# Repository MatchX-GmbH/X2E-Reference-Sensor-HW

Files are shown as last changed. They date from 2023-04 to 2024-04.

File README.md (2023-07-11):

# MatchX X2E Reference Sensor

## Introduction

MatchX X2E Reference Design is a universal platform to help you start your custom X2E application. It is completely open source so you can use it as a starting point for development and testing of your custom LPWAN sensor. It provides all hardware and software features to kickstart your development including LoRa (SubGHz and 2.4GHz) radios, set of sensors and GPS receiver. It is built around the ESP32-S3 module and has a friendly Arduino-compatible form factor.

## Hardware

The main features of the board include:

- ESP32-S3-MINI-1-N4R2 based, 4MB flash, 1MB PSRAM
- Arduino compatible pinout
-  Two LoRa radios: LoRa Sub-GHz and LoRa 2.4GHz
- USB-C power and debug/programming
- Grove and Stemma sensor expansion connectors
- GPS module
- Accelerometer, Air Quality, Humidity, Pressure and Temperature sensors
- Li-Ion battery connector, 2mm pitch
- Li-Ion battery charger and battery monitoring
- Ultra low Iq switching power supply for long battery operation
- User and reset buttons
- ESP-IDF programmable

## Pinout

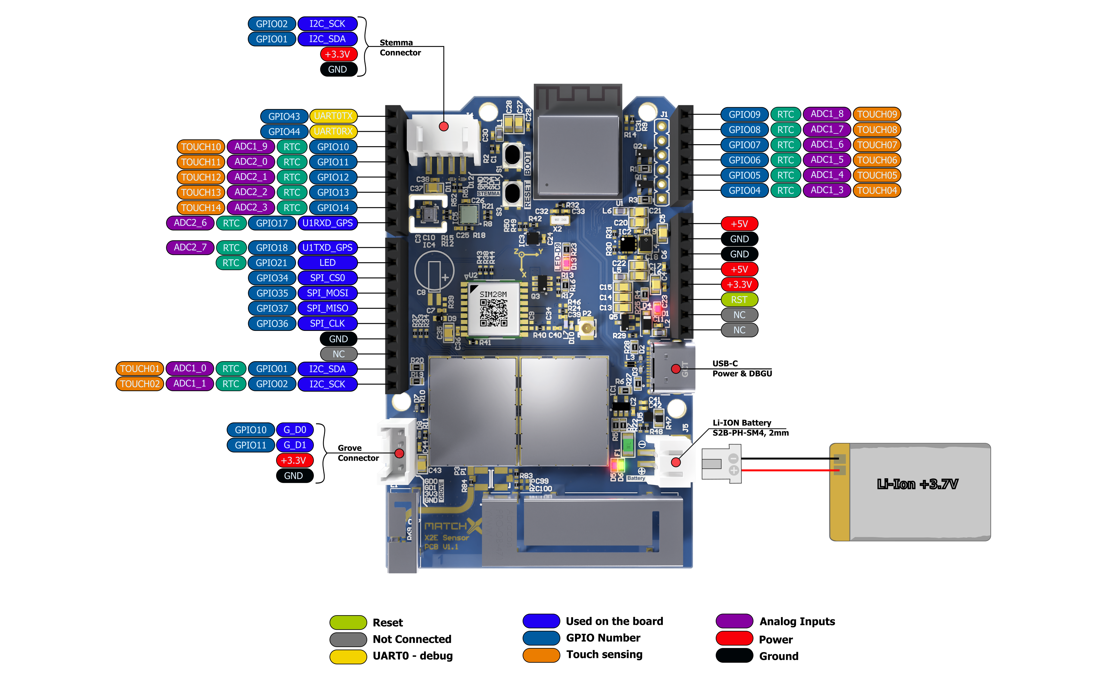
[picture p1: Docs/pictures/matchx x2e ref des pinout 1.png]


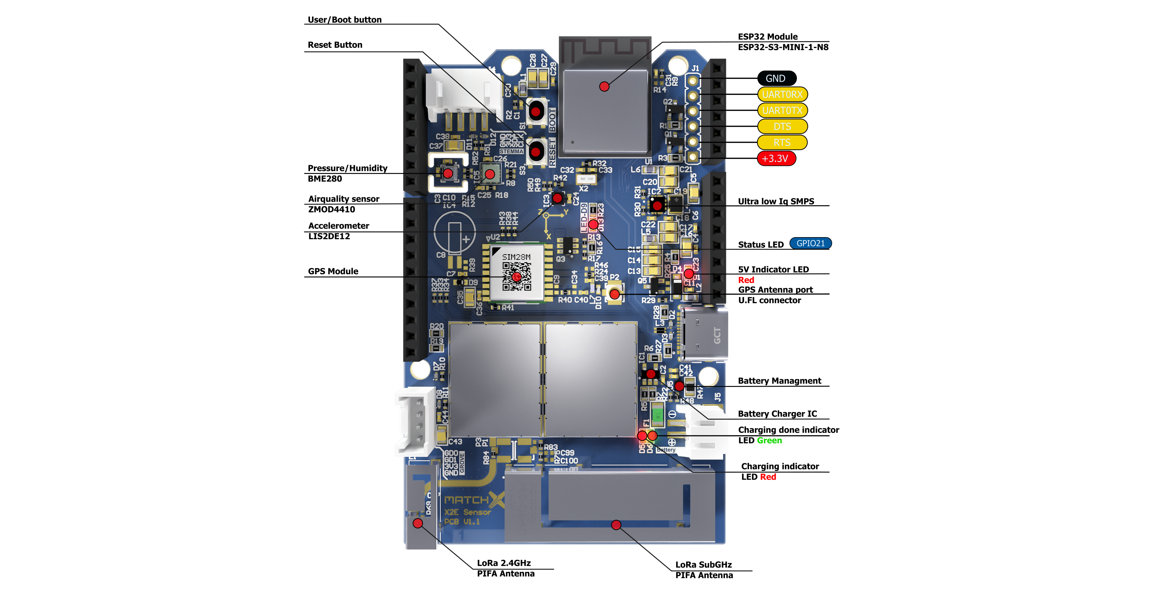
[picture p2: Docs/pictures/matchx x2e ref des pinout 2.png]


## Software

The software reference design can be found here:

## Realated documents

[ESP-IDF programming guide](https://docs.espressif.com/projects/esp-idf/en/latest/esp32s3/get-started/index.html)

[ESP32-S3 Datasheet](https://www.espressif.com/sites/default/files/documentation/esp32-s3_datasheet_en.pdf) (PDF)

[Semtech SX1261 Product Details](https://www.semtech.com/products/wireless-rf/lora-connect/sx1261) 

[Semtech SX1280 Product Details](https://www.semtech.com/products/wireless-rf/lora-connect/sx1280) 

[Low-power wide-area network - Wikipedia](https://en.wikipedia.org/wiki/Low-power_wide-area_network)

[MXCzkEVM MEP-802 Github](https://github.com/MXCzkEVM/MEPs/blob/main/proposals/mep-802.md)

## Contact Us
https://matchx.io/pages/contact-us

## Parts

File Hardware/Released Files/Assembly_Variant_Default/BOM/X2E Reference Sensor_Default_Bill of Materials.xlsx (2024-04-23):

Fitted | Designator | Quantity | Value | Description | Footprint | Manufacturer | Manufacturer Part Number | PartNumber
 | AN1 | 1 |  | Rf Ant 868MHZ/915MHZ Stamped Met | XDCR_PRO-OB-471 | Proant | PRO-OB-471
 | AN2 | 1 |  | 2.4GHz Bluetooth, WirelessHART, WLAN, Zigbee Stamped Metal RF Antenna 2.4GHz ~ 2.5GHz Solder Surface Mount | XDCR_PRO-OB-440 | Abracon | PRO-OB-440
 | C1, C3, C6, C10, C11, C23, C24, C25, C26, C29, C36, C38, C39, C44, C82, C83, C95, C96 | 18 | 100 nF | CAP, CERM, 100 nF, 50V, +/- 10%, X7R, 0402 | C0402 |  | GRM155R71H104KE14J
 | C2, C18, C19, C22, C30, C31, C41, C81, C93, C102 | 10 | 1uF/10V | CAP, CERM, 1 uF, 10V, +/- 10%, X5R, 0402 | C0402 |  | C0402C105M8PACTU
 | C4, C5, C13, C14, C15, C16, C17, C20, C21, C27, C28, C35, C37, C43, C94, C103 | 16 | 10uF | CAP, CERM, 10uF, 16V, +/- 20%, X5R, 0805 | C0805 |  | GRM21BR61C106KE15L
 | C7 | 1 | 1uF/10V | CAP, CERM, 1 uF, 10V, +/- 10%, X5R, 0402 | C0402
 | C32, C33 | 2 | 12pF | CAP, CERM, 12pF, 16V, +/- 5%, C0G/NP0, 0402 | C0402 |  | GRM0225C1C120GA03L
 | C40, C79 | 2 | 47pF | CAP, CERM, 47pF, 16V, +/- 5%, C0G/NP0, 0402 | C0402 |  | 885012005029
 | C42 | 1 | 2.2uF | CAP, CERM, 2.2uF, 10V, +/- 10%, X5R, 0402 | C0402 |  | GRM155R61A225KE01D
 | C80 | 1 | 47 nF | CAP, CERM, 47nF, 16V, +/- 10%, X7R, 0402 | C0402 |  | GCM155R71C473KA37D
 | C84 | 1 | 100pF | CAP, CERM, 100pF, 16V, +/- 5%, C0G/NP0, 0402 | C0402 |  | 885012005031
 | C86, C101 | 2 | 470nF | CAP, CERM, 470nF, 16V, +/- 10%, X7R, 0402 | C0402 |  | MSASE105AB5474KFNA01
 | C89, C97, C98 | 3 | 10nF | CAP, CERM, 10nF, 16V, +/- 10%, X7R, 0402 | C0402 |  | C0402C103J4RAC
 | C90 | 1 | 1nF | CAP, CERM, 1nF, 16V, +/- 10%, X7R, 0402 | C0402 |  | C0402C102K4RAC
 | D1 | 1 |  | Red 625nm LED Indication - Discrete 2V 0603 (1608 Metric) | LED0603 | Wurth Electronics | 150060RS75000
 | D2, D3, D7, D8, D11, D12 | 6 |  | TVS DIODE 5V 9.8V SOD923 | SOD-923 | ON Semiconductor | ESD9L5.0ST5G
 | D4 | 1 |  | DIODE GEN PURP 400V 1A SOD123F | sod123f | Diodes Incorporated | US1GWF-7
 | D5 | 1 |  | LED Low-Power Uni-Color Red 639nm 2V 2-Pin Chip LED T/R | LED0603_RA | Vishay Lite-On | LTST-S270KRKT
 | D6, D13 | 2 |  | LED GREEN CLEAR 0603 R/A SMD / LED Uni-Color Green 574nm 2-Pin Chip LED T/R | LED0603_RA | Vishay Lite-On | LTST-S270KGKT
 | D10 | 1 |  | TVS DIODE 15 V 0402 | T0402 | Murata | LXES1UTAA1-157
 | F1 | 1 | 108mR | Fuse Chip Slow Blow Acting 1A 63V SMD Solder Pad 1206 T/R UL | F1206 | Bourns | SF-1206S100-2
 | FL1 | 1 |  | Impedance-matched Filter For Sem | FP-0900FM15D0039E-MFG | Johanson | 0900FM15D0039E
 | FL2 | 1 |  | RF Filter - Lowpass | LP_FILTER_JOHANSON | Johanson | 0868LP15A020E
 | FL3 | 1 |  | Rf Filter 2.4GHZ-2.5GHZ 0402 | JT=2450FM07D0034T | Johanson | 2450FM07D0034T
 | FL4 | 1 |  | Rf Filter Low Pass 2.4GHZ 0402 | JT=2450LP07C0100T | Johanson | 2450LP07C0100T
 | IC1 | 1 |  | IC CONTROLLR LI-ION 4.2V SOT23-5 | SOT23-5 | Microchip | MCP73831T-2ATI/OT
 | IC2 | 1 |  | DC to DC Converter Buck-Boost 2.6V 1.6A 12-Pin WLP T/R | 14-FC2QFN | Maxim | MAX77827DEFD+T
 | IC3 | 1 |  | Accelerometer X, Y, Z Axis ±2g, 4g, 8g, 16g 0.5Hz ~ 2.69kHz 12-LGA (2x2) | LGA12C50P4X4_200X200X100 | STMicroelectronics | LIS2DE12TR
 | IC4 | 1 |  | SENSOR PRESSURE HUMIDITY TEMP | LGA65P250X250-8 | Bosch | BME280
 | IC5 | 1 |  | Indoor Air Quality Sensor | ZMOD4xxx_AI1_Standard | Renesas | ZMOD4410_AI1
 | IC6 | 1 |  | IC RF TxRx Only General ISM < 1GHz LoRaWAN 150MHz ~ 960MHz 24-VFQFN Exposed Pad | QFN50P400X400X80_HS-25N_Semtech | Semtech | SX1261IMLTRT
 | IC7 | 1 |  | RF Switch IC WLAN 6GHz 50 Ohm 6-QFN (1x1) | QFN50P100X100X50-6N | Skyworks Solutions | SKY13453-385LF
 | IC8 | 1 |  | IC RF TxRx Only 802.15.4 LoRa™ 2.4GHz 24-WFQFN Exposed Pad | QFN50P400X400X80_HS-25N_Semtech | Semtech | SX1280IMLTRT
 | IC9 | 1 |  | Single cell pack/system-side CEDV battery fuel (gas) gauge w/pre-programmed chemistry profiles 9-DSBGA -40 to 85 | IC_BQ27421YZFR-G1A | Texas Instruments | BQ27220YZFR
 | J2 | 1 |  | Conn USB 2.0 Type C RCP 24 POS 0.3mm/0.5mm Solder RA SMD 24 Terminal 1 Port T/R | TYPE-CF-16P-RAT-L7.3 | Global Connector Technology | USB4105-GF-A
 | J3 | 1 |  | 4 Positions Header Connector 0.079" (2.00mm) Through Hole Tin | CON-NS-TECH_1125S-4P | Seeed Studio | 110990030
 | J4 | 1 |  | CONN HEADER SMD R/A 4POS 2MM | JST S4B-PH-SM4-TB | JST Sales America Inc. | 1734827-4
 | J5 | 1 |  | CONN HEADER R/A 2POS 2MM | CON_S2B-PH-K-S | JST | S2B-PH-K-S(LF)(SN)
 | J6, J9 | 2 |  | Arduino Template | Arduino-C, Arduino-A | Harwin | M20-7820842
 | J7 | 1 |  | Arduino Template | Arduino-B | Harwin | M20-7820646
 | J8 | 1 |  | Arduino Template | Arduino-D | Harwin | M20-7821042
 | L1, L2, L5, L6, L15, L17 | 6 |  | Ferrite Beads 0603 600ohms 1.3A DCR=.15ohms | L0603 | Murata Electronics North America | BLM18KG601SH1D
 | L3 | 1 | DLP11SA350HL2L | Common Mode Filters / Chokes 35Ohm 20% 100MHz | DLP11SA350HL2L | Murata Electronics | DLP11SA350HL2L
 | L4 | 1 | 1uH/4.1A | FIXED IND 1UH 4.1A 42 MOHM SMD | L252020 | Pulse | BDHE002520121R0MQ1
 | L7 | 1 | 27nH | Inductor, Wirewound, 27 nH, 280mA , 520mOhm, SMD | L0402 | Murata | LQW15AN27NJ00D
 | L12, L14 | 2 | 47nH | Inductor, Wirewound, 47nH, 210 mA, 1.08Ohms, ±0.2nH, SMD | L0402 | Murata | LQW15AN47NJ00D
 | L13 | 1 | 15uH | Inductor, 15Uh, 0.25A, Multilayer Rohs Compliant: Yes | L0805_ML | Murata | LQM21DN150M70L
 | L16 | 1 | 15uH | Chip inductor, 15uH, 250mA, 950mOhm, 0805 | L0805_ML | TDK | MLZ2012M150WTD25
 | P2 | 1 |  | CONN UMCC JACK STR 50OHM SMD | CON_U.FL | TE Connectivity AMP Connectors | 1909763-1
 | Q1, Q2 | 2 |  | MOSFETN-CH 30V 6.2A SOT23-3 | SOT-23 | Diodes | DMN3023L-7
 | Q3 | 1 |  | Trans MOSFET N/P-CH 20V 1.34A/1.14A Automotive 6-Pin SOT-26 T/R | SOT23-6 | Diodes | DMC2700UDM-7
 | Q5 | 1 |  | MOSFET P-CH 12V 4.3A SOT-23 | SOT-23 | Infineon Technologies Americas Corp. | IRLML6401TRPBF
 | R1, R3, R16 | 3 | 1k | RES, 1k, 1%, 0.063 W, 0603 | R0603 |  | AC0603FR-101KL
 | R2, R9, R35, R36, R42, R48, R70, R79 | 8 | 10k | RES, 10k, 1%, 1/16 W, 0402 | R0402 |  | RE0402FRE0710KL
 | R4, R5 | 2 | 3k9 | RES, 3k9, 1%, 0.063 W, 0603 | R0603
 | R6 | 1 | 3k | RES, 3k, 1%, 0.063 W, 0603 | R0603 |  | AF0603FR-073KL
 | R7, R23 | 2 | 2k | RES, 2k, 1%, 0.063 W, 0603 | R0603 |  | RE0603FRE072KL
 | R8, R12, R15, R21, R30, R31, R39, R40, R49, R50, R69, R75, R83, R84 | 14 | 0R | RES, 0R, 1%, 1/16 W, 0402 | R0402 |  | AC0402FR-070RL
 | R10, R11, R24, R51, R52 | 5 | 10R | RES, 10R, 1%, 1/16 W, 0402 | R0402 |  | RC0402FR-0710RP
 | R13, R17, R29, R32 | 4 | 1M | RES, 1M, 1%, 1/16 W, 0402 | R0402 |  | RC0402FR-101ML
 | R18 | 1 | 100k | RES, 100k, 1%, 1/16 W, 0402 | R0402 |  | AC0402FR-13100KL
 | R22 | 1 | 1k | RES, 1k, 1%, 0.063 W, 0603 | R0603
 | R26 | 1 | 1k | RES, 1k, 1%, 1/16 W, 0402 | R0402
 | R27, R28 | 2 | 5k1 | RES, 5k1, 1%, 0.063 W, 0603 | R0603 |  | AC0603FR-135K1L
 | R33, R34, R37, R38, R43, R44, R72, R73, R74, R76, R77, R78 | 12 | 22R | RES, 22R, 1%, 1/16 W, 0402 | R0402 |  | RC0402FR-0722RP
 | R41 | 1 | 47k | RES, 47k, 1%, 1/16 W, 0402 | R0402 |  | RC0402FR-1347KL
 | R47 | 1 | 0.01R | RES, 10 mOhm, 1%, 1/8W, 0805 | R0805 |  | RL0805FR-070R01L
 | R71 | 1 | 100R | RES, 100R, 1%, 1/16 W, 0402 | R0402 |  | RC0402FR-13100RL
 | S1, S3 | 2 |  | Switch Tactile N.O. SPST Button 12VDC 50mA 5N SMD T/R | TS-1108A | Alps Alpine | SKRPASE010
 | SH1, SH2 | 2 |  | Shield - EMI Gasket - Standard Surface Mount Shields 14.9x18.5x2mm | SHIELD_MSTICK_SOM
 | U1 | 1 |  | WLAN-BLE Module – 802.11 SMD Module, ESP32-S3FH4R2 with 4 MB Flash Die, 2MB PSRAM, PCB Antenna | ESP32-S3-MINI-1-N4R2 | Espressif Systems | ESP32-S3-MINI-1-N4R2
 | U2 | 1 | GT-1110-UB7X | GPS, GLONASS, QZSS and SBAS Module | SIM28ML | GOTOP | GT-1110-UB7X
 | Y1 | 1 | 32.768kHz | XTAL SMD 3215, 32.768kHz, 7pF, ±20ppm | XTAL_3215 | Epson Timing | FC-135 32.7680KA-AC0
 | Y2 | 1 | 32MHz | 32MHz ±10ppm Crystal 10pF 50 Ohms 4-SMD 2016, No Lead | nd2016da | ECS International | ECS-320-10-37B-CKY
 | Y3 | 1 | 52MHz | 52 MHz Crystal 10pF 50 Ohms 4-SMD, No Lead | nd2016da | ECS | ECS-520-12-37B-CTN-TR

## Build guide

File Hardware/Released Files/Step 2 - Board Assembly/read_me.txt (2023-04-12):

Place following files here:

- Mechanical Drawing (Board dimensions, holes position, ..)
- TOP and BOTTOM Assembly Drawing (Component position with Reference Designator)
- TOP and BOTTOM VIEW (shows board outline, assembly layer, TOP + BOTTOM layers)
- Bill of Materials (grouped by component type)
- Component reference BOM (each component on one line: Designator, Description, Manufacturer 1,
  Manufacturer, Part Number 1, Package / Case, Supplier 1, Supplier Part Number 1)
- Pick and Place
- TOP and BOTTOM Layer + TOP and BOTTOM Paste Gerber Files (for stencil - if panel is done in a PCB house, ask them later for the top/bottom layers and paste for the panel)
- PDF 3D Model

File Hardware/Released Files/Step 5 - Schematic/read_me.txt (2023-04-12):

Update Schematic Cover Page to RELEASED DD-MMM-YYYY
Place here PDF version of schematic, if possible one for each BOM variant.

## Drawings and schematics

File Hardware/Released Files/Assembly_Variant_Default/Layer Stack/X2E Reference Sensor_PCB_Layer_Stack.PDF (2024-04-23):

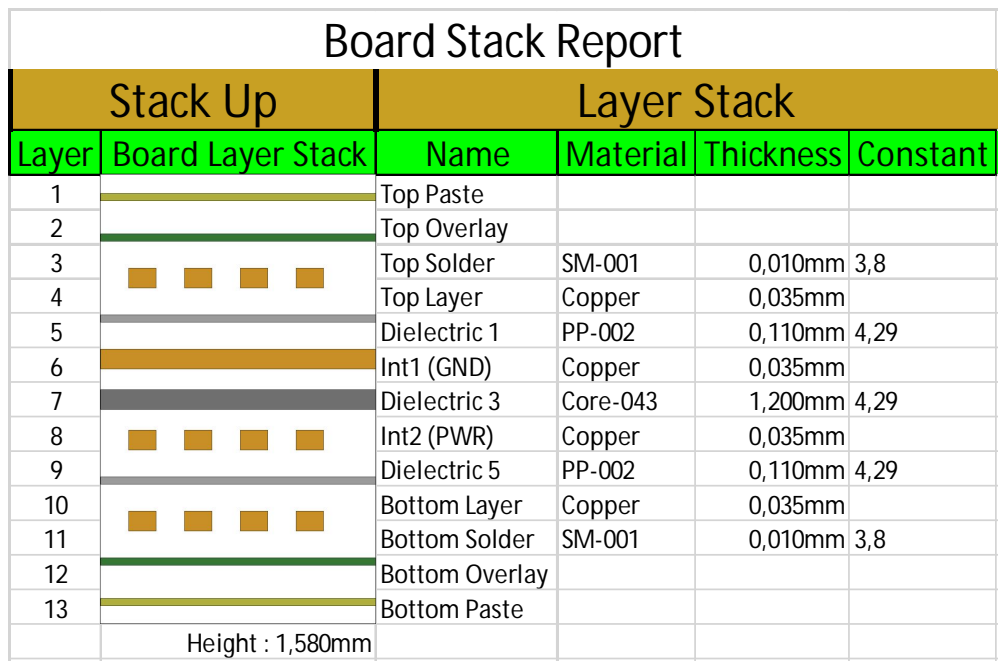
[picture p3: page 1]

Stack Up | Layer Stack
Layer | Board Layer Stack | Name | Material | Thickness | Constant
1 | | Top Paste
2 | | Top Overlay
3 | | Top Solder | SM-001 | 0,010mm | 3,8
4 | | Top Layer | Copper | 0,035mm
5 | | Dielectric 1 | PP-002 | 0,110mm | 4,29
6 | | Int1 (GND) | Copper | 0,035mm
7 | | Dielectric 3 | Core-043 | 1,200mm | 4,29
8 | | Int2 (PWR) | Copper | 0,035mm
9 | | Dielectric 5 | PP-002 | 0,110mm | 4,29
10 | | Bottom Layer | Copper | 0,035mm
11 | | Bottom Solder | SM-001 | 0,010mm | 3,8
12 | | Bottom Overlay
13 | | Bottom Paste

Height : 1,580mm

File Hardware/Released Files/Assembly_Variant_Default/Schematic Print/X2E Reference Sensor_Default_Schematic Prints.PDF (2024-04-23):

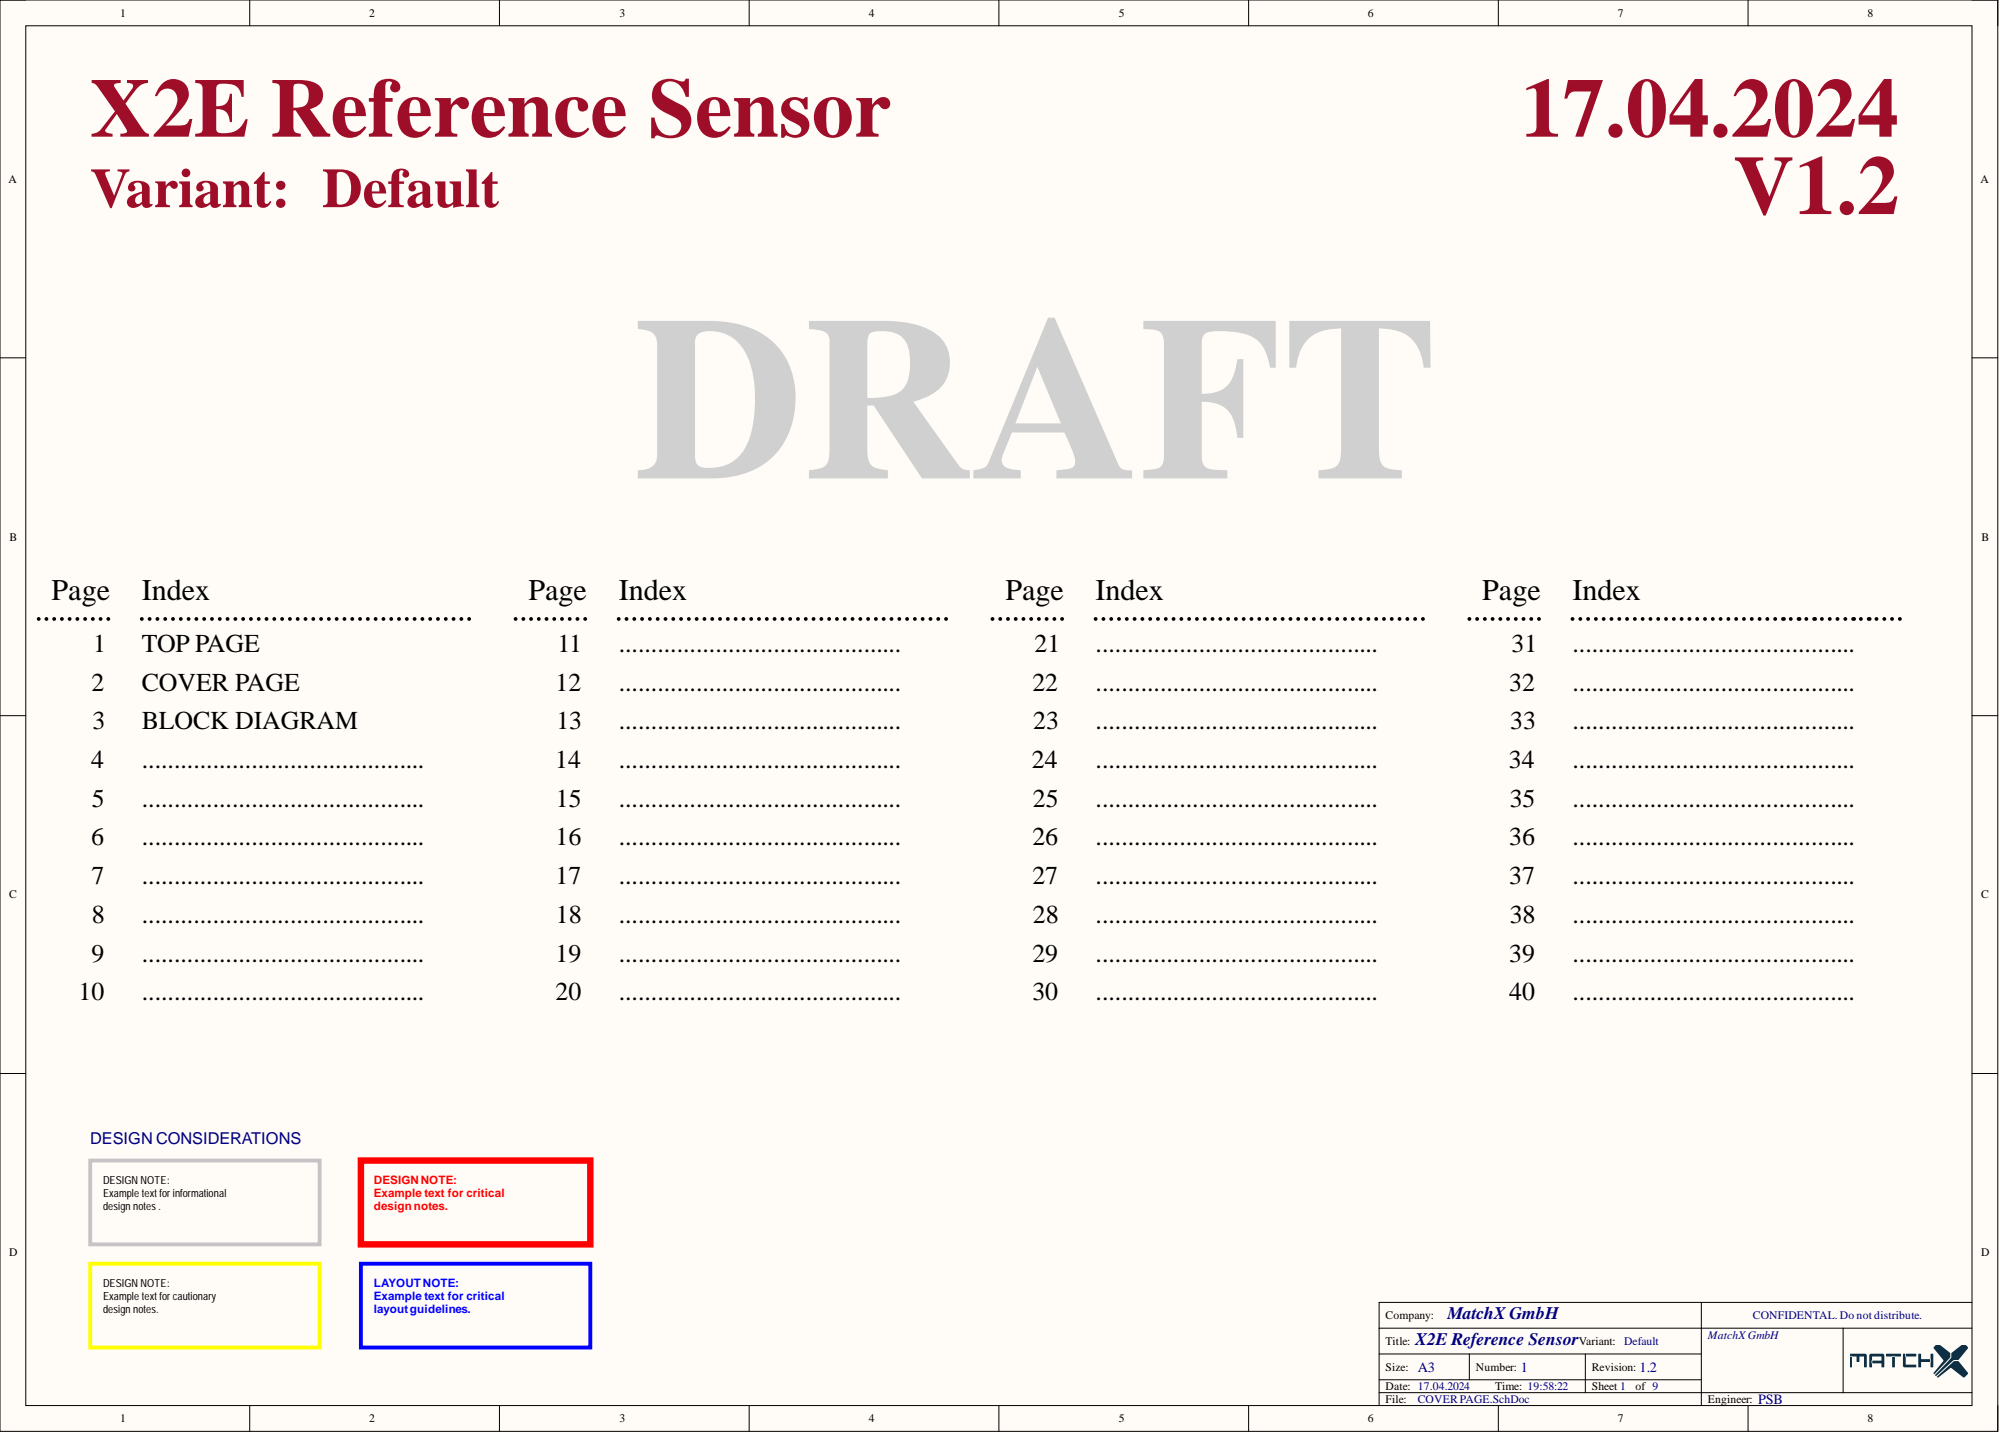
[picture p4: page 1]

DESIGN NOTE:
Example text for informational
design notes .

Example text for critical
design notes.

Example text for cautionary

LAYOUT NOTE:
layout guidelines.

CONFIDENTAL. Do not distribute.

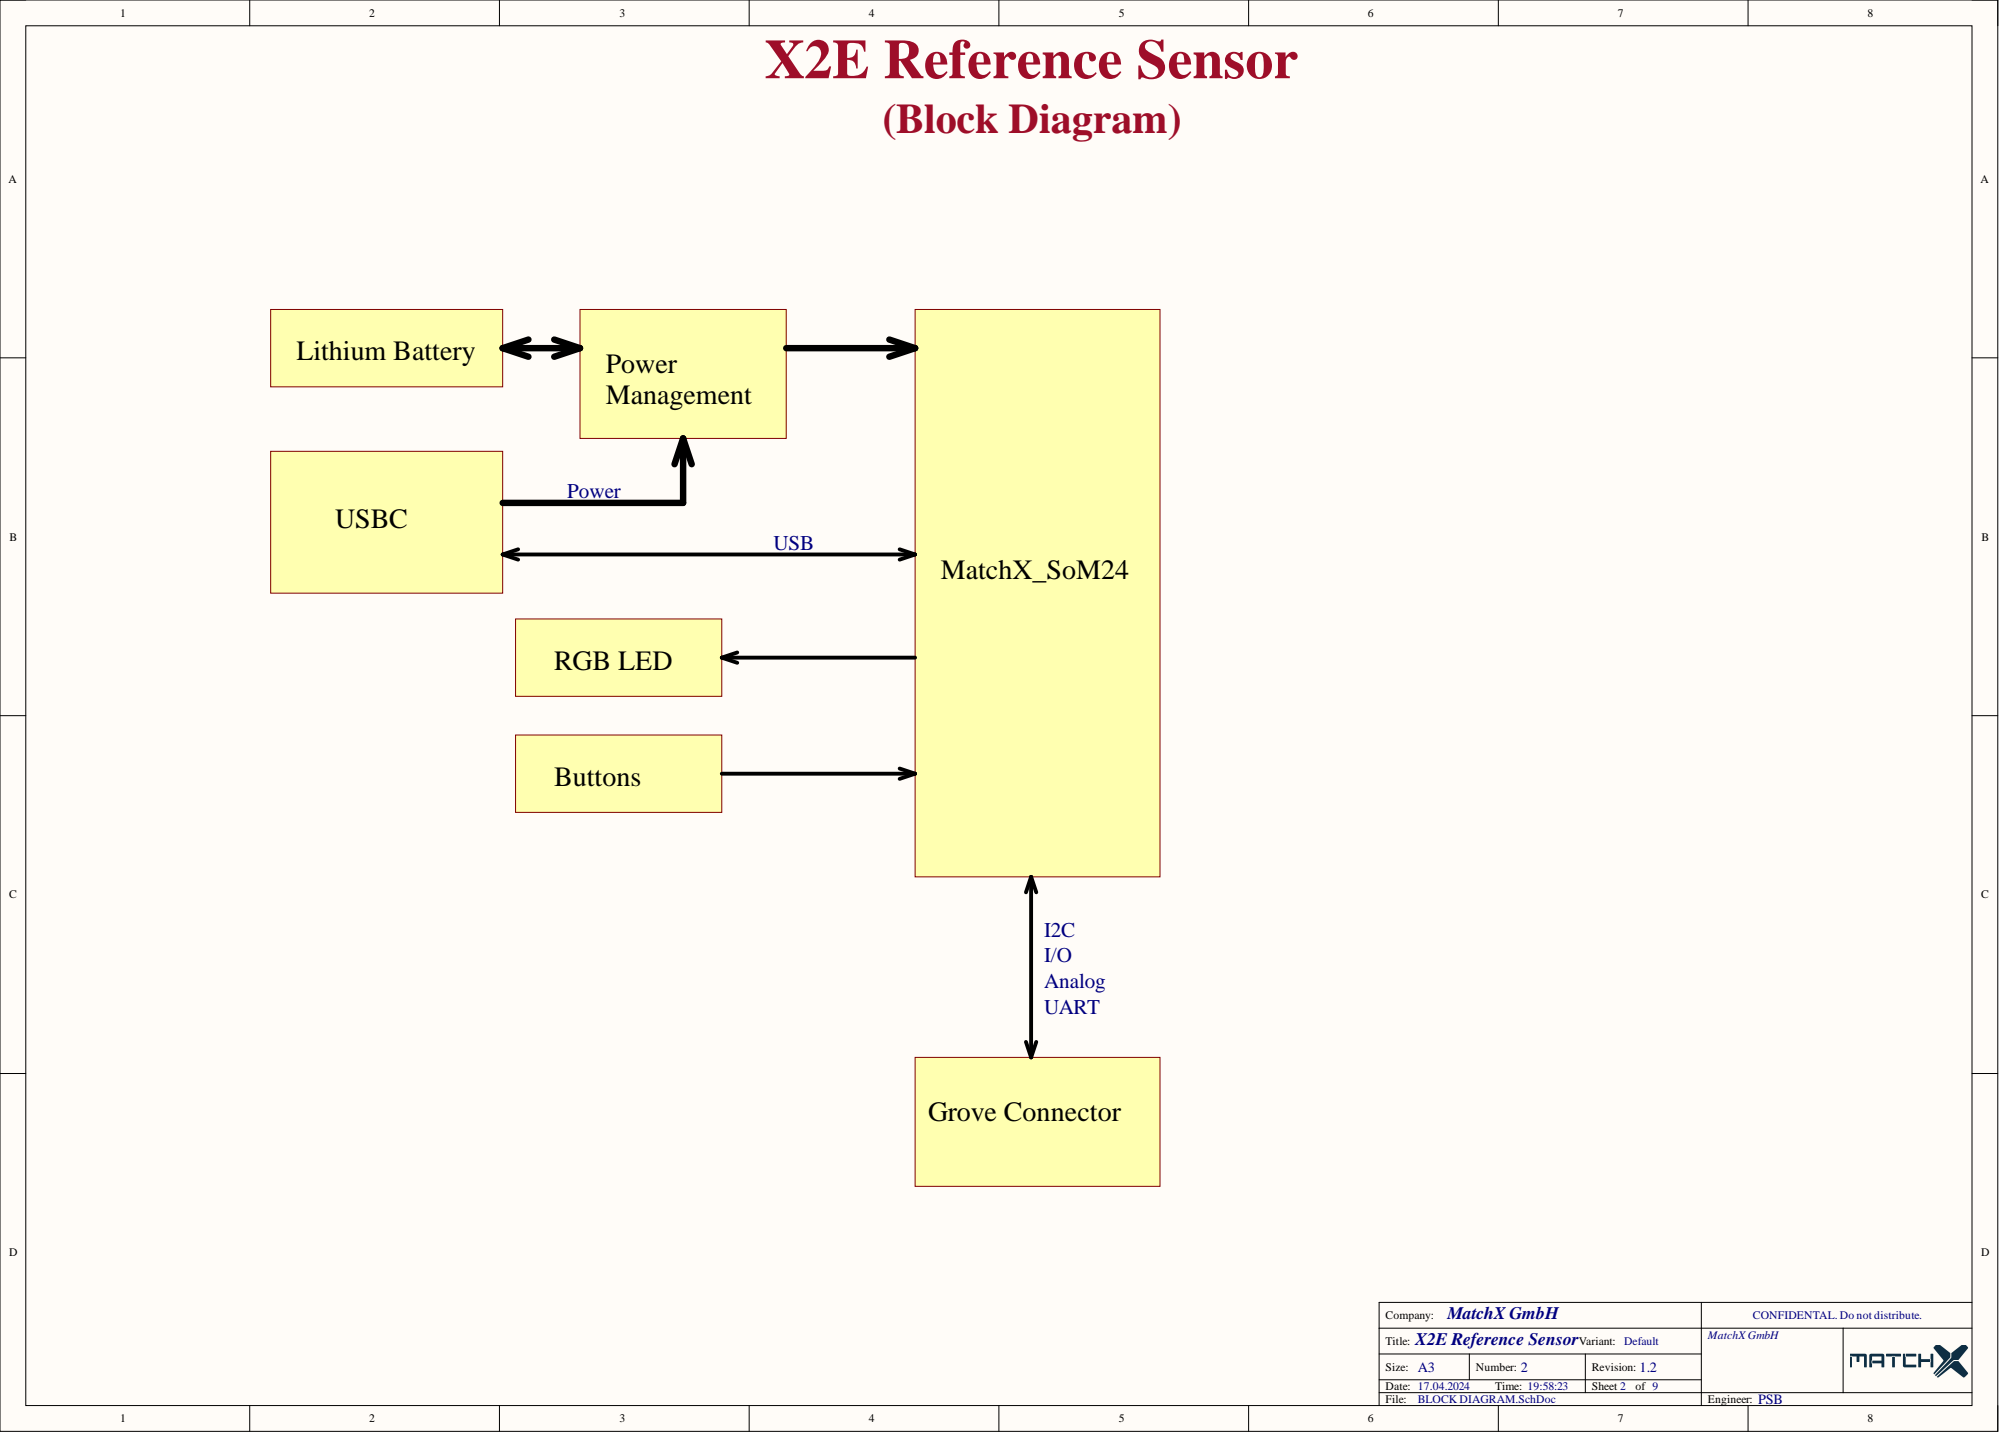
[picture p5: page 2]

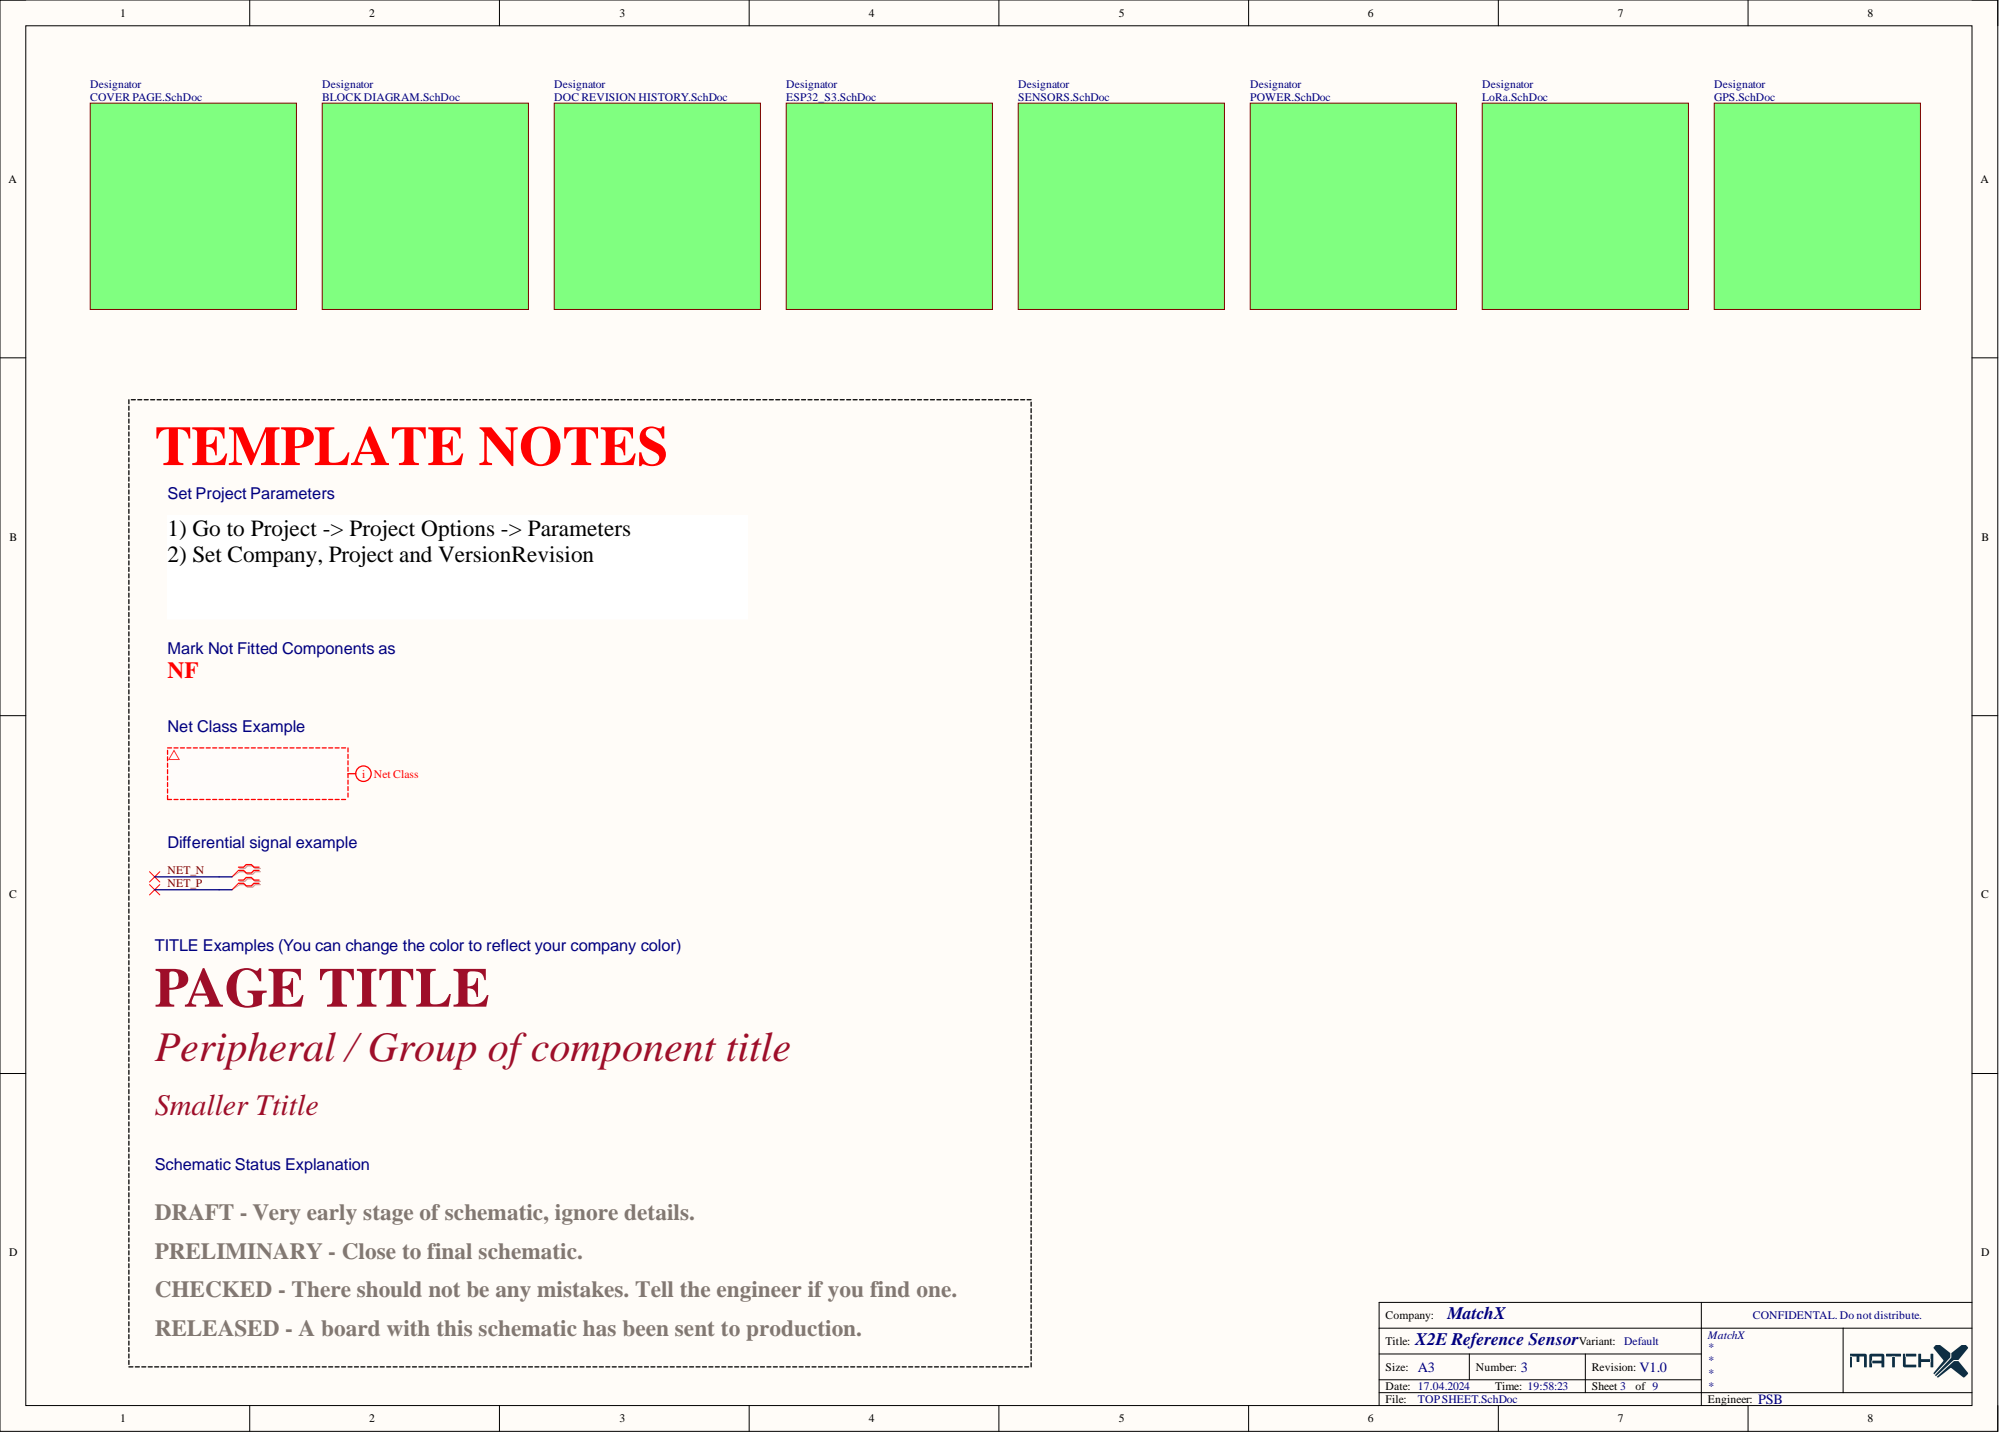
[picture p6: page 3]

Designator
DOC REVISION HISTORY.SchDoc

Set Project Parameters
1) Go to Project -> Project Options -> Parameters
2) Set Company, Project and VersionRevision

Mark Not Fitted Components as

TITLE Examples (You can change the color to reflect your company color)

DRAFT - Very early stage of schematic, ignore details.
PRELIMINARY - Close to final schematic.
CHECKED - There should not be any mistakes. Tell the engineer if you find one.
RELEASED - A board with this schematic has been sent to production.

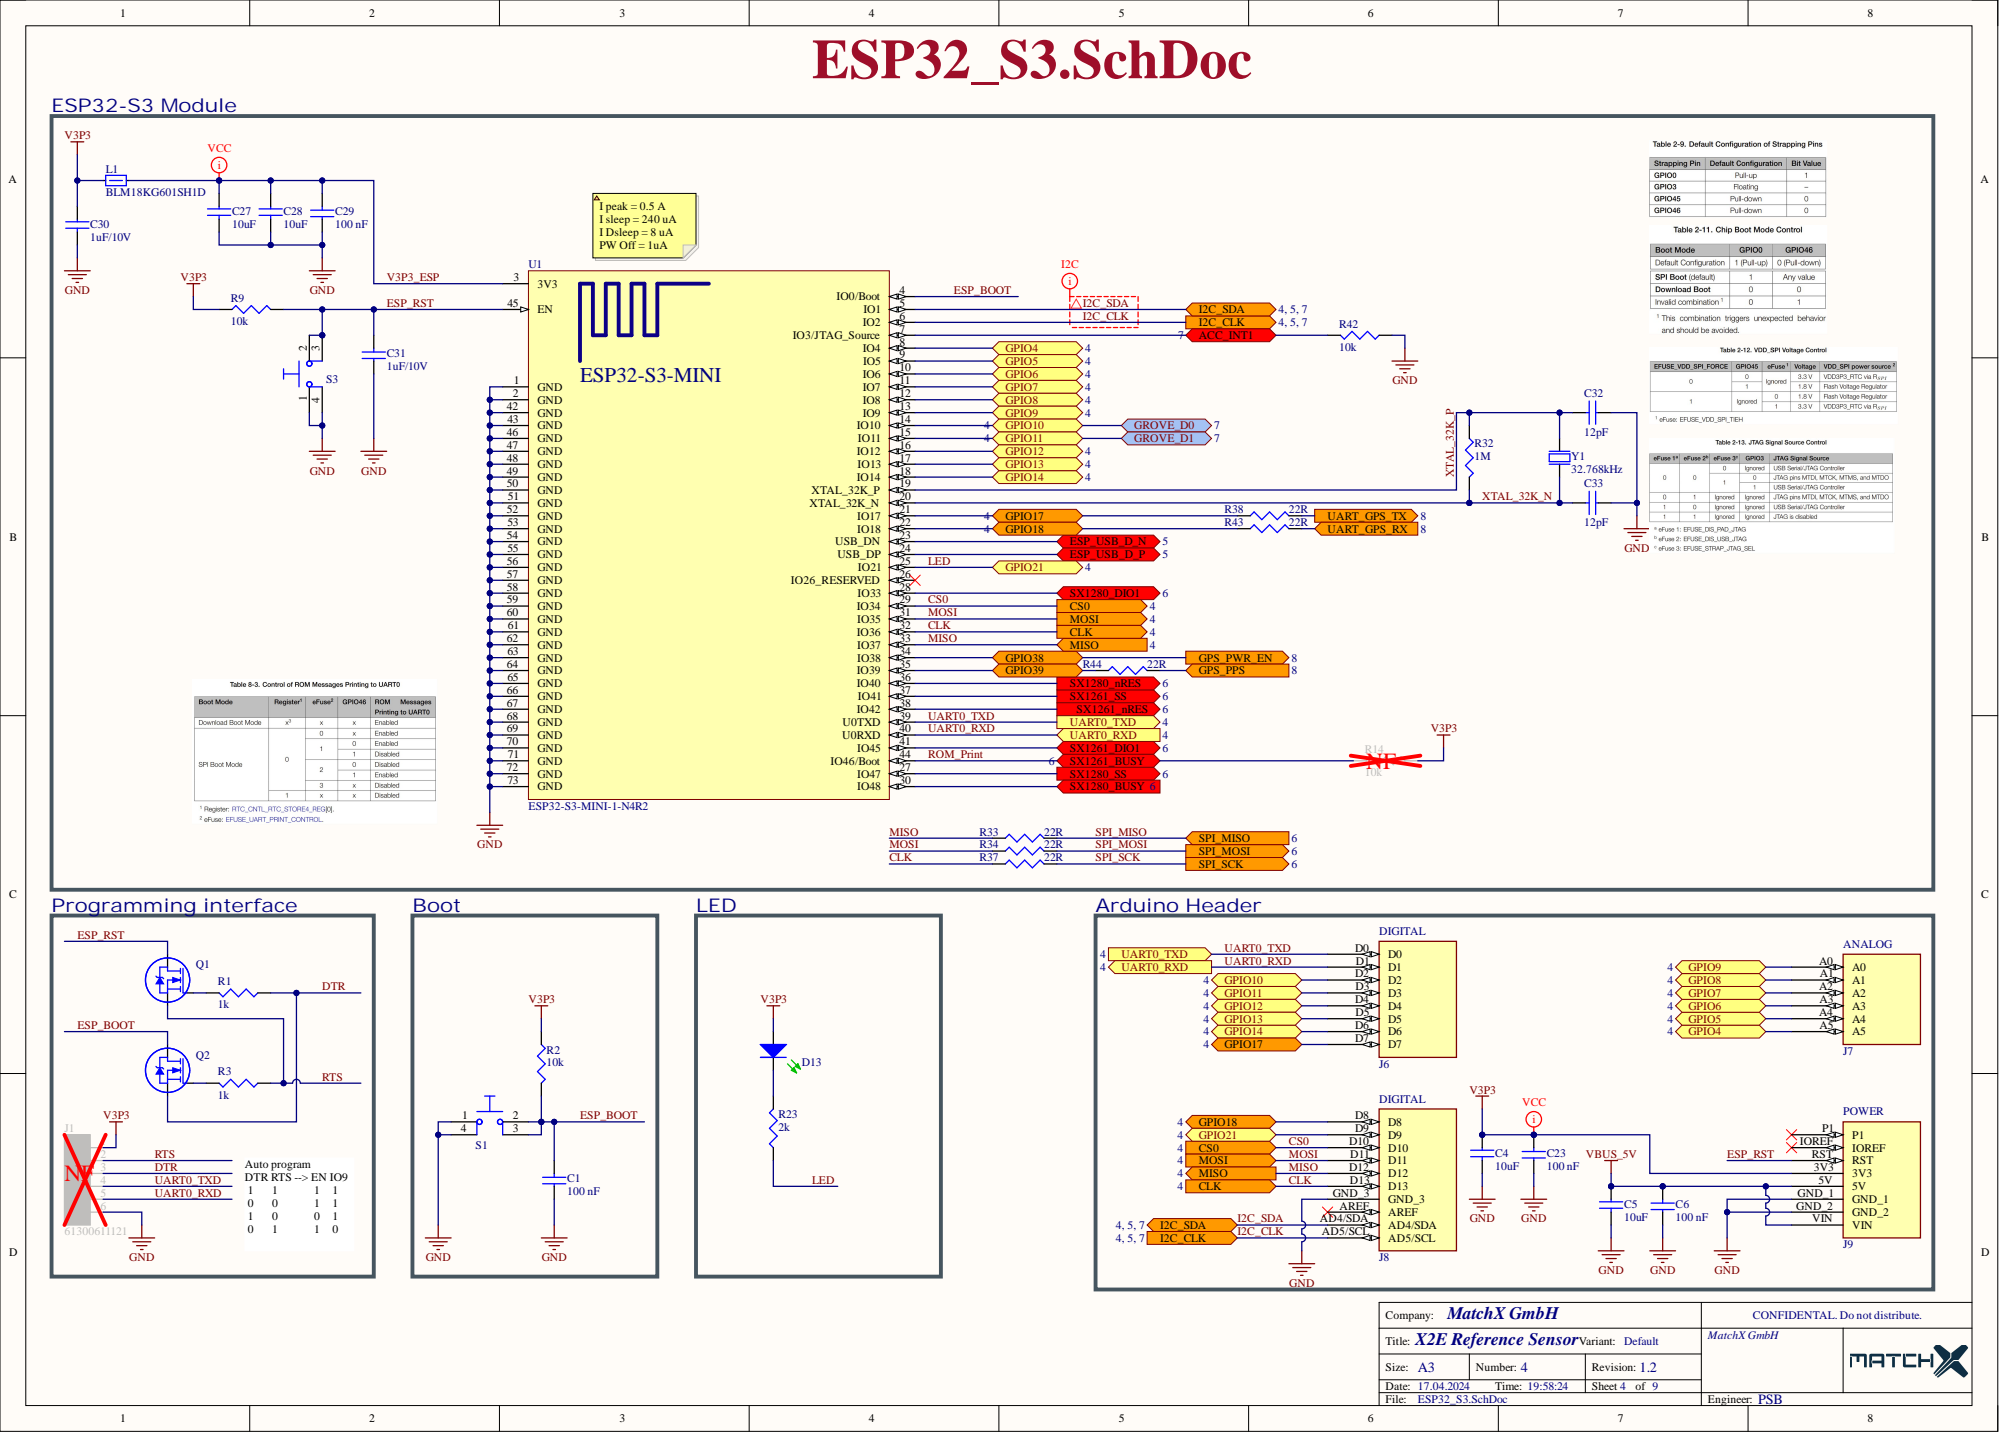
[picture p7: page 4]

4 2

5 1 | 2 0
5 2 | V 3 MISO R3 3 2 2 R SPI_MIS O SPI_MIS O 6 MOSI R3 4 2 2 R SPI_MO S I SPI_MO S I 6 CL K R3 7 2 2 R SPI_SC K SPI_SC K 6

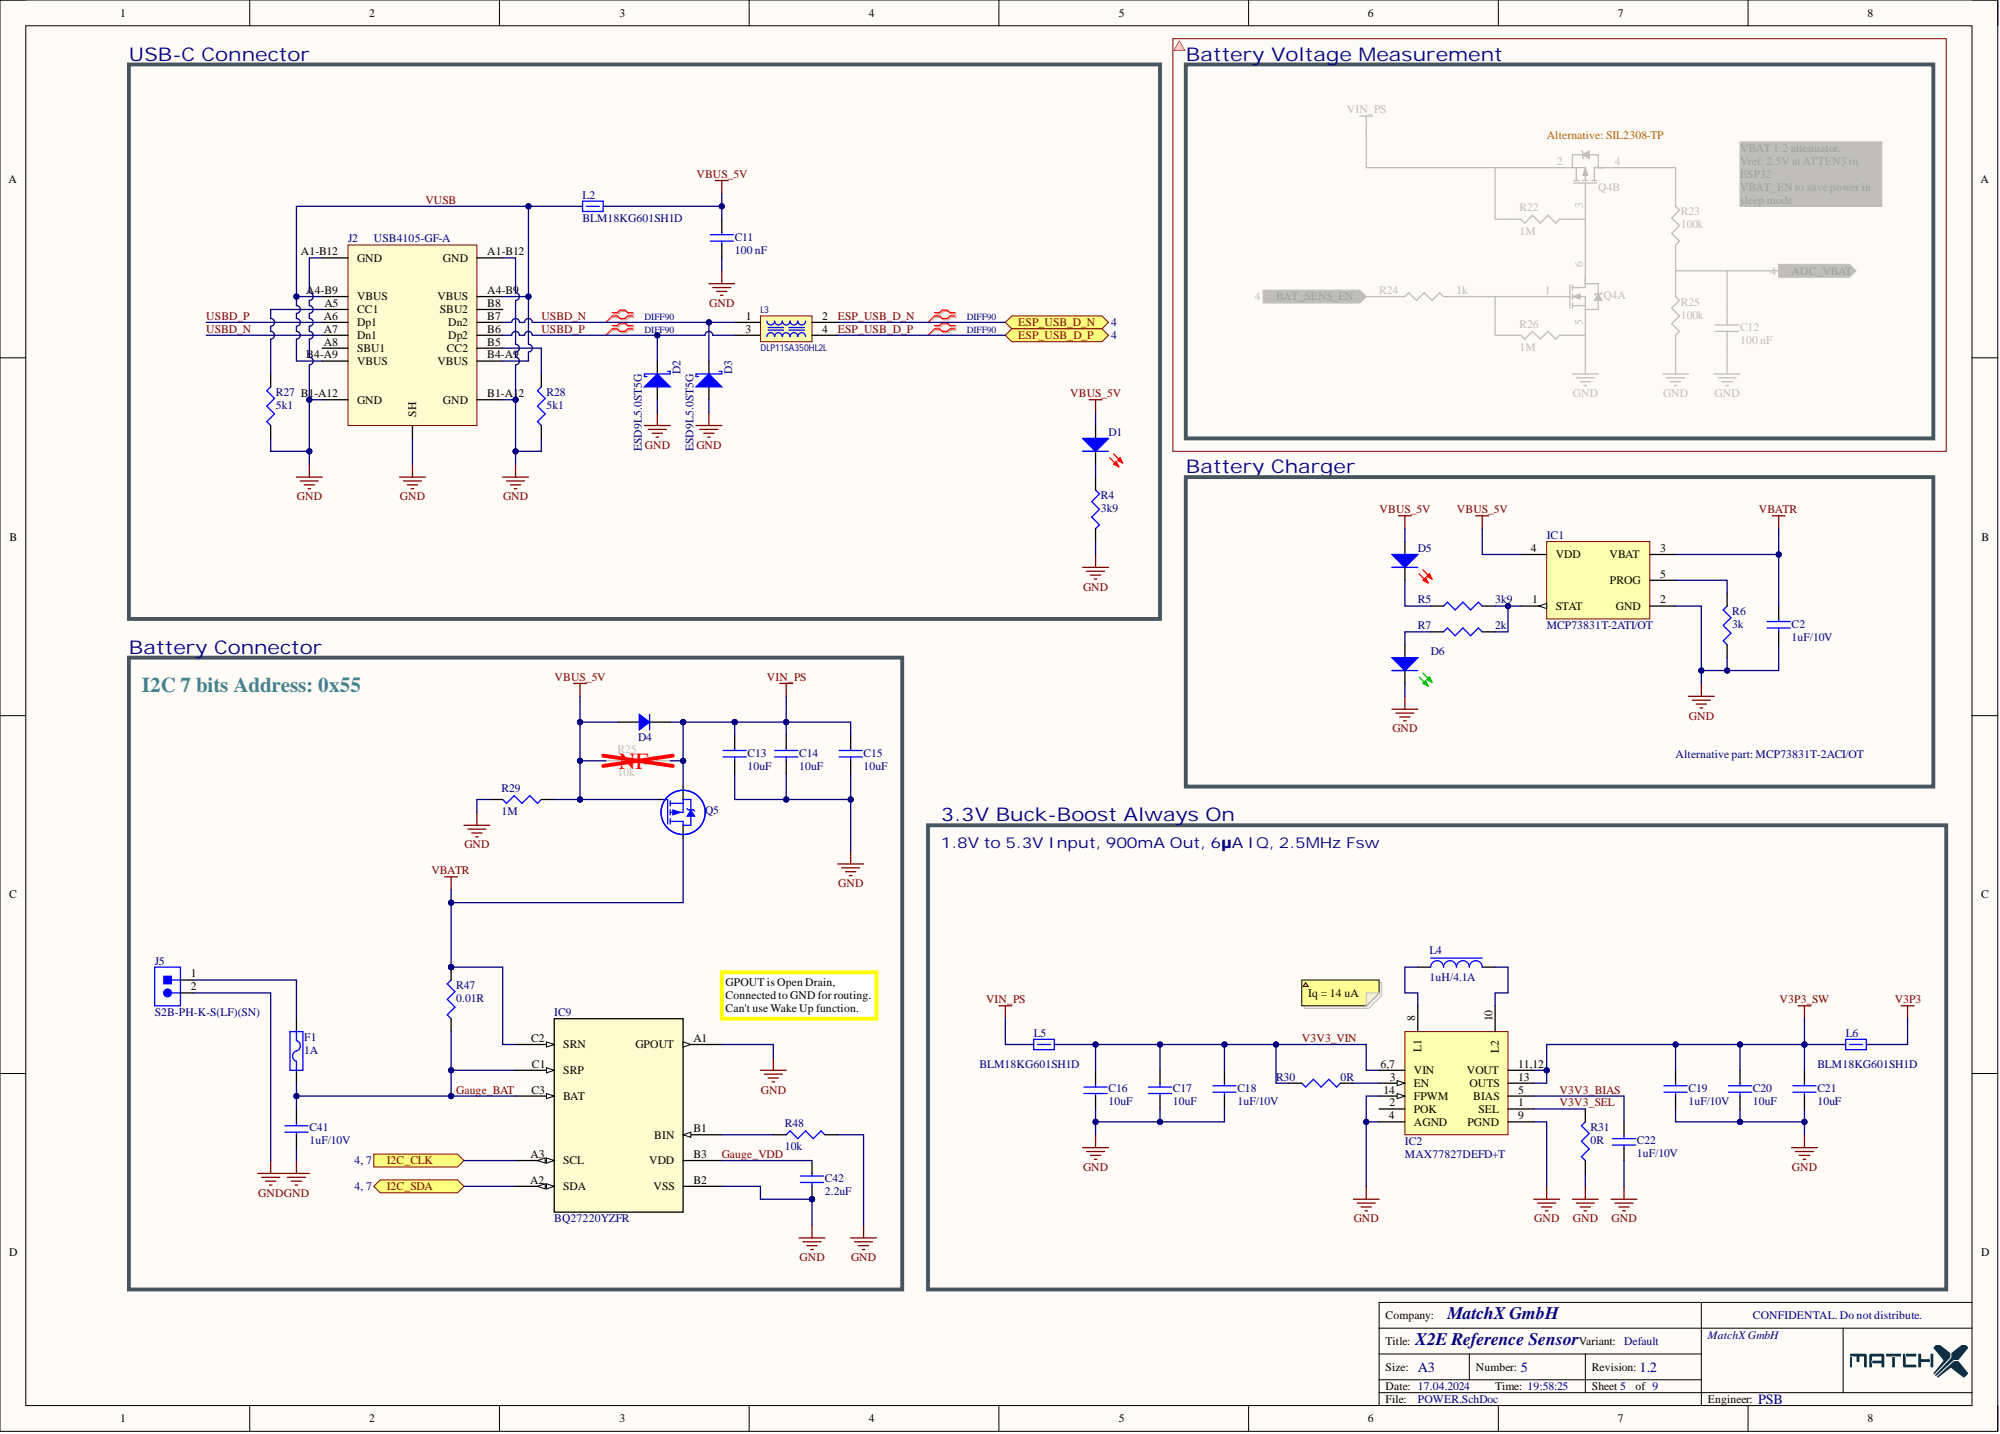
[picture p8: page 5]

VBAT 1:2 attenuator.
Vref: 2.5V at ATTEN3 in
ESP32
VBAT_EN to save power in
sleep mode

3.3V Buck-Boost Always On

1.8V to 5.3V Input, 900mA Out, 6μA IQ, 2.5MHz Fsw

GPOUT is Open Drain,
Connected to GND for routing.
Can't use Wake Up function.

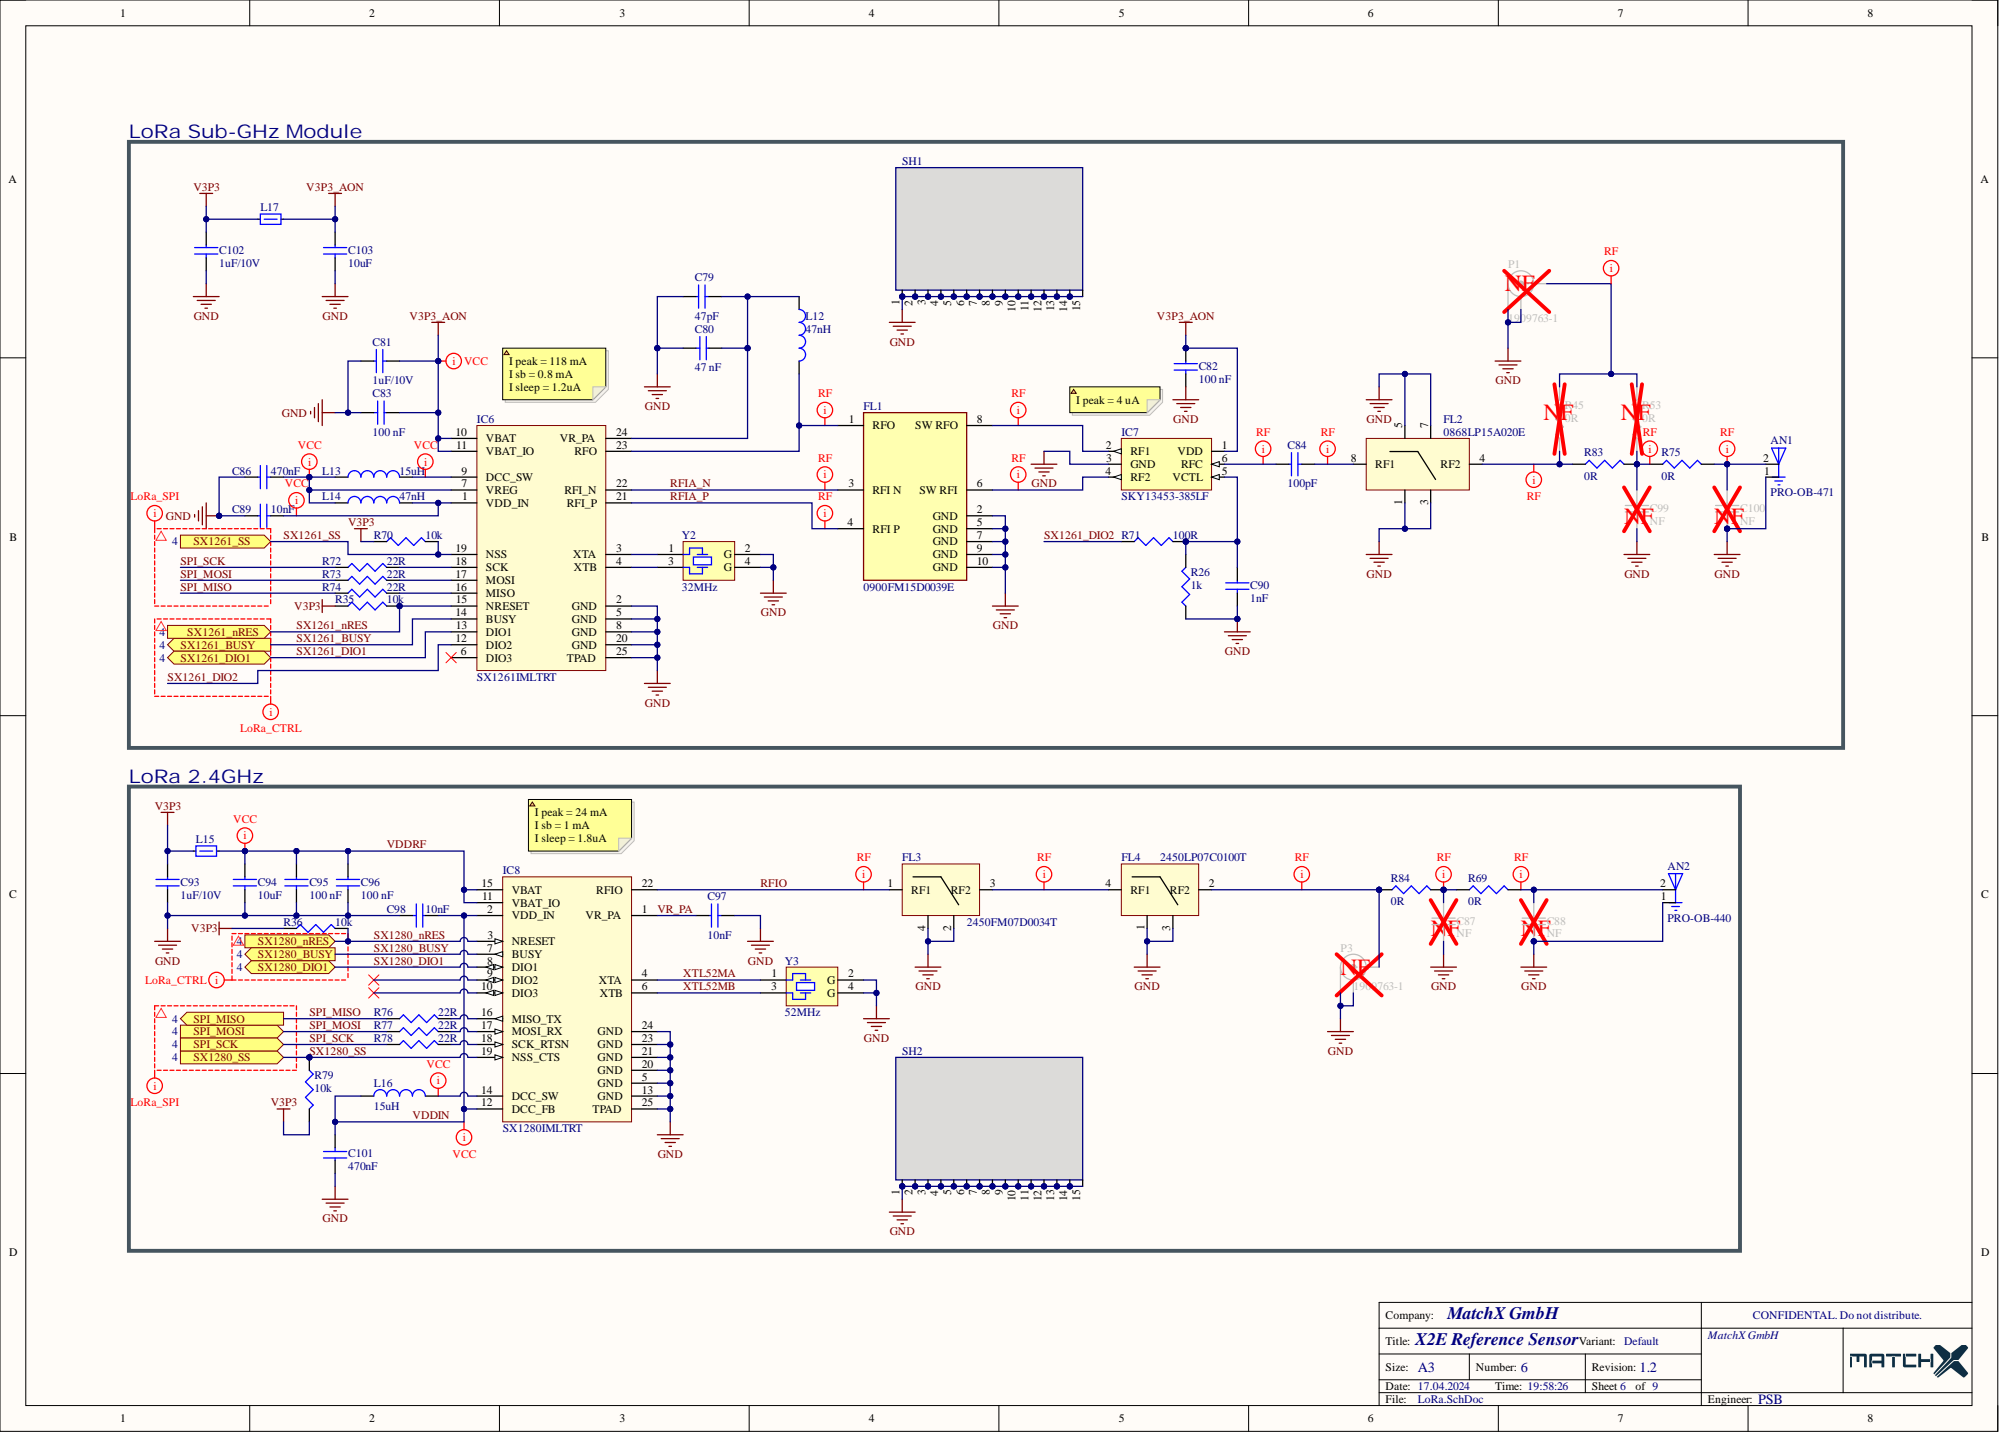
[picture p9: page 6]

LoRa Sub-GHz Module

NRESET 3

SX1280_BUSY | BUSY 7
SX1280_DIO1 | DIO1 8

MISO_TX 16

SCK_RTSN 18

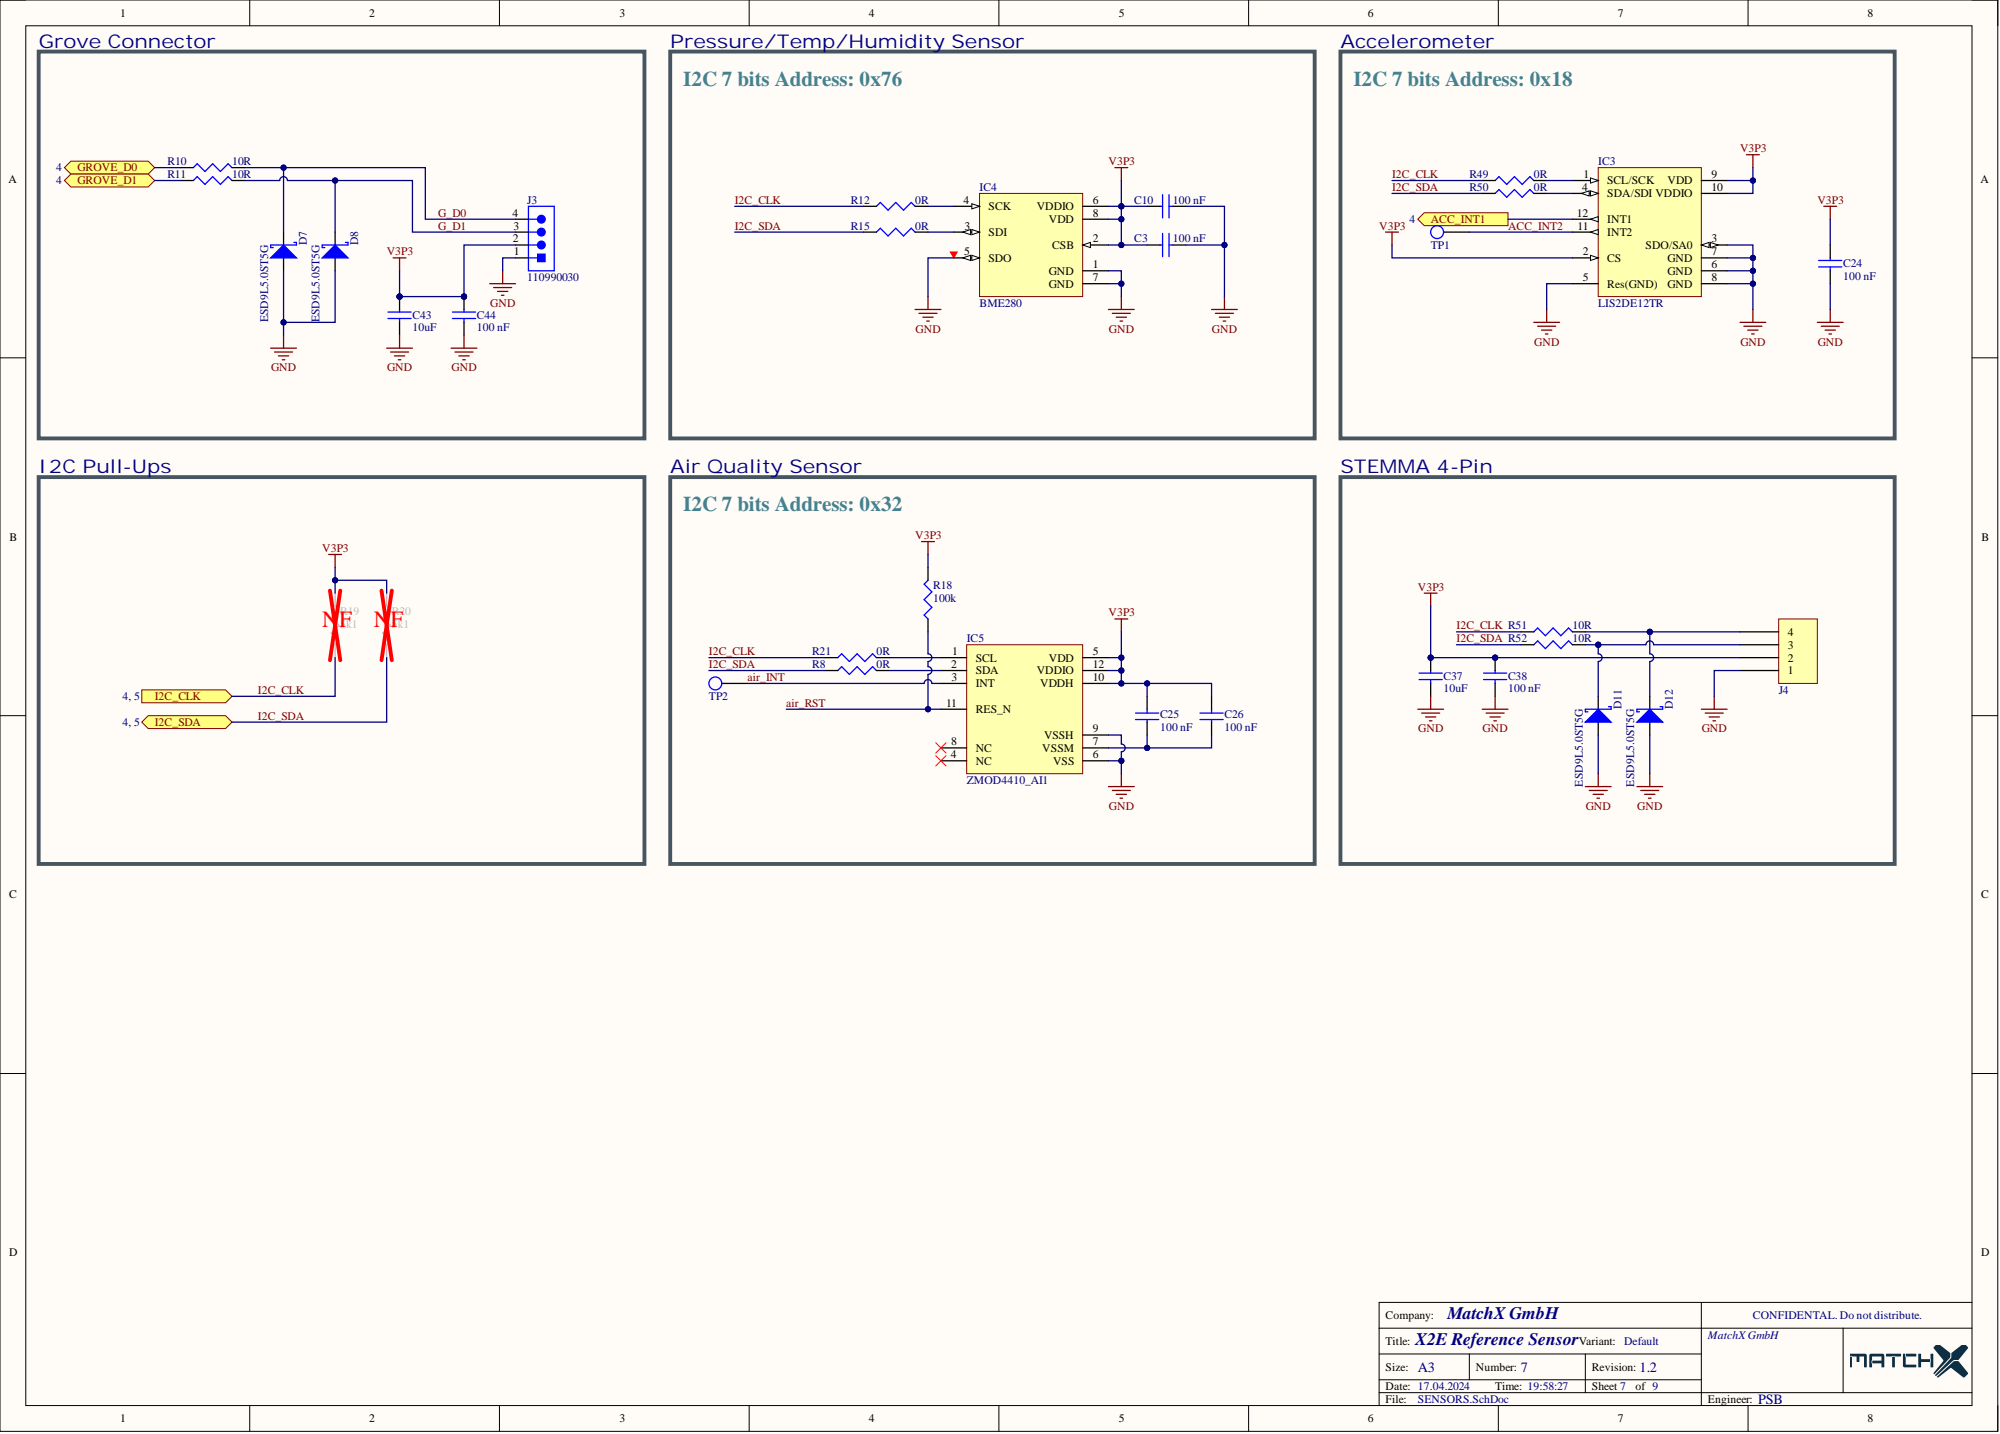
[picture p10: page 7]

Pressure/Temp/Humidity Sensor

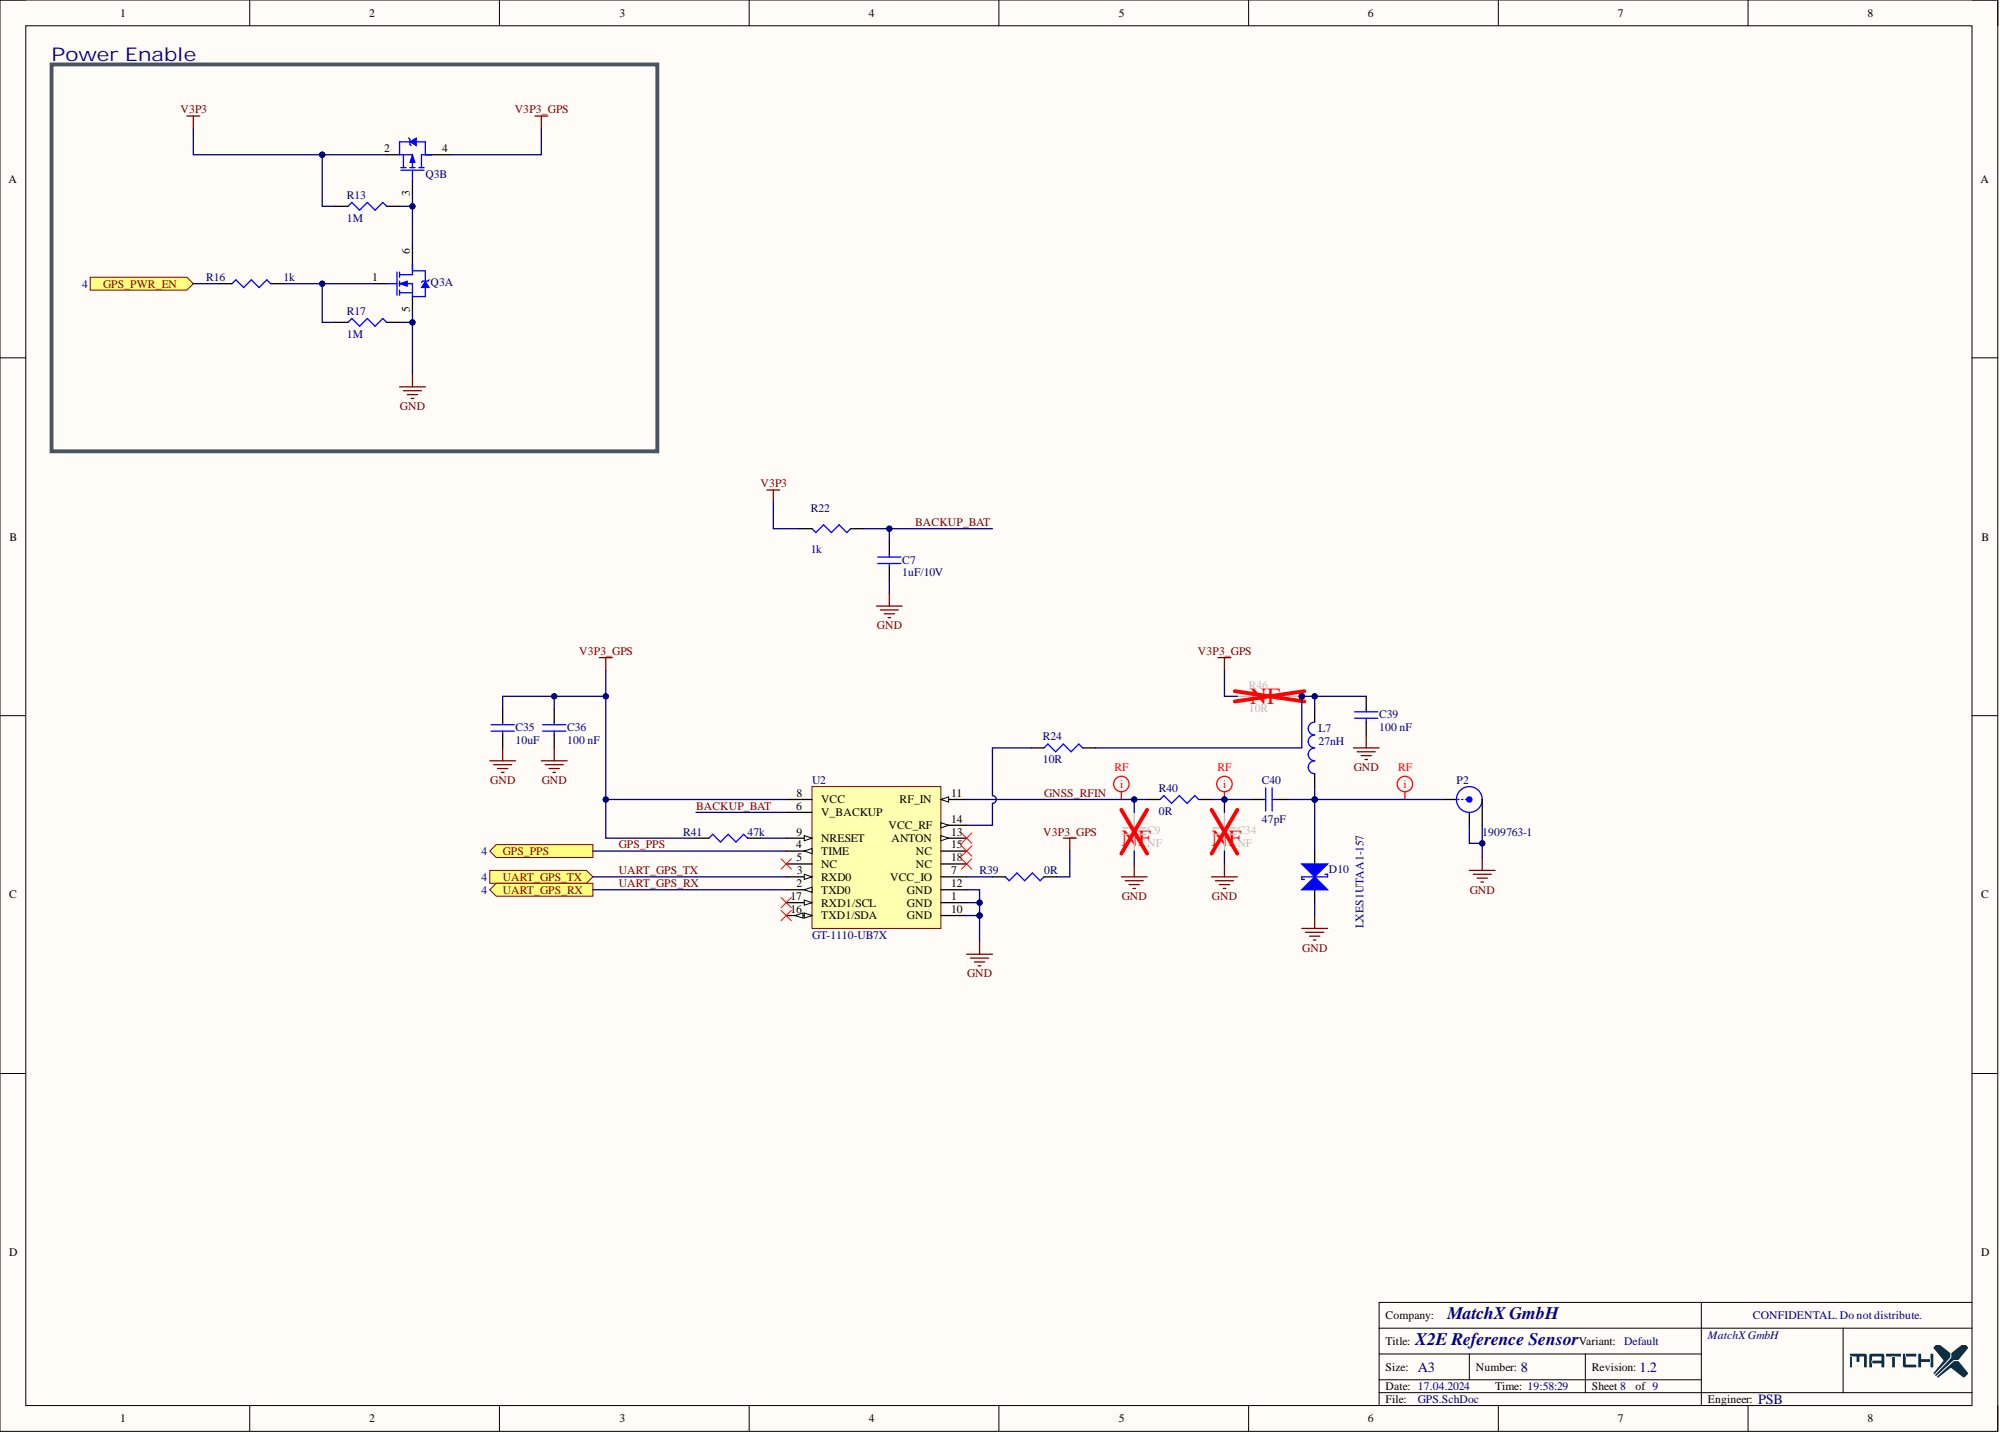
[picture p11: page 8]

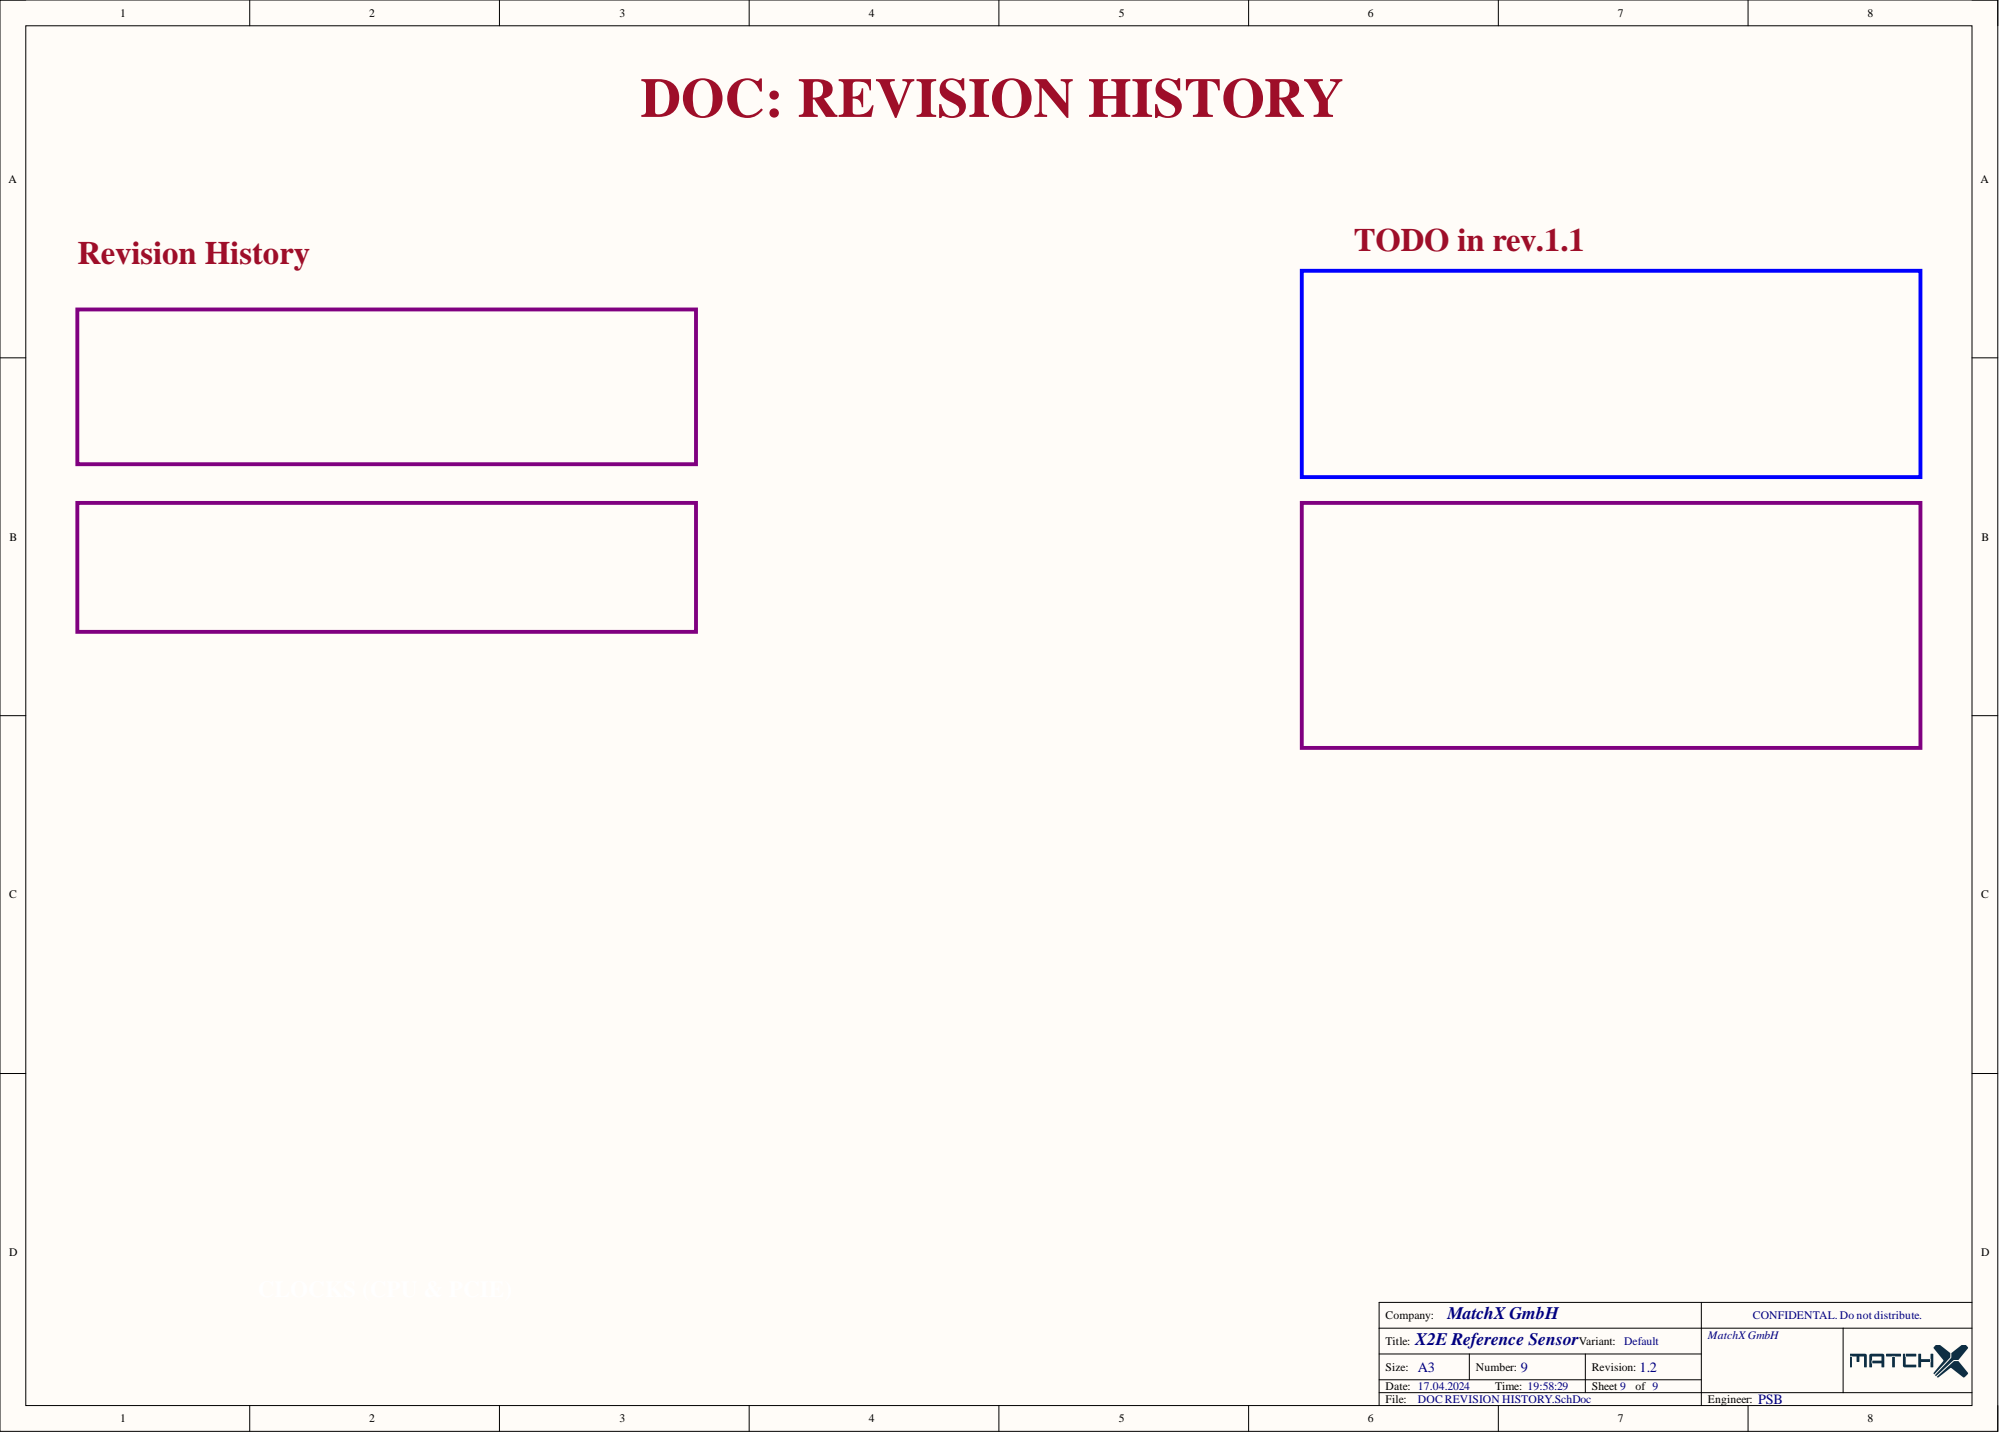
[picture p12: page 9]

TODO in rev.1.1 Revision History

DOC REVISION HISTORY.SchDoc

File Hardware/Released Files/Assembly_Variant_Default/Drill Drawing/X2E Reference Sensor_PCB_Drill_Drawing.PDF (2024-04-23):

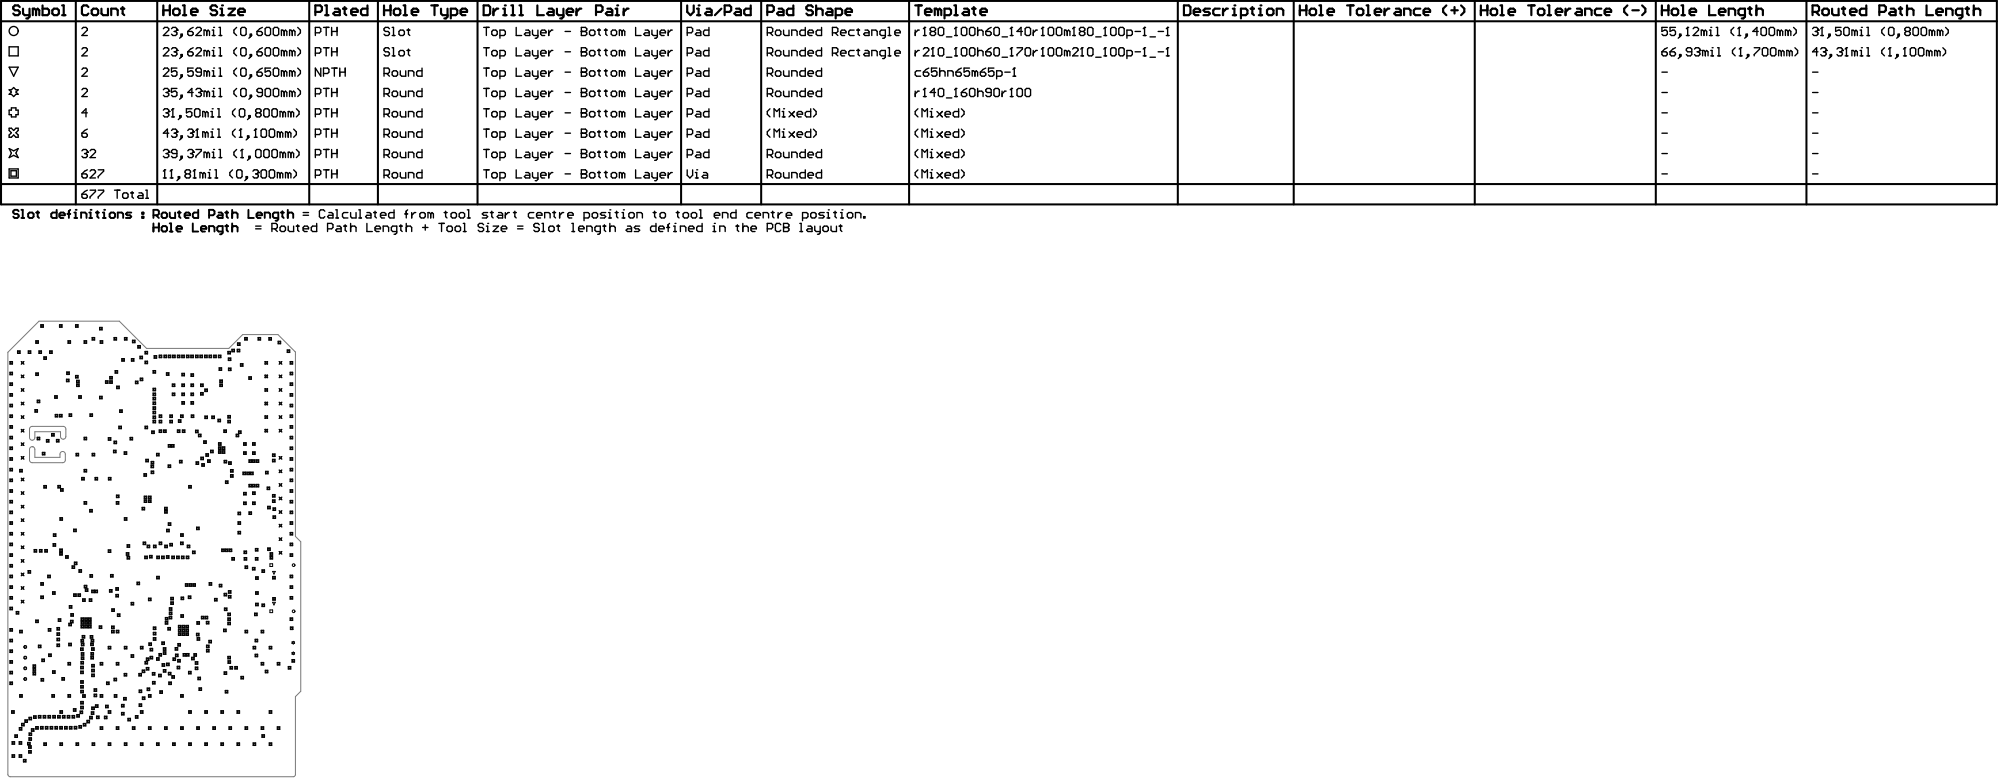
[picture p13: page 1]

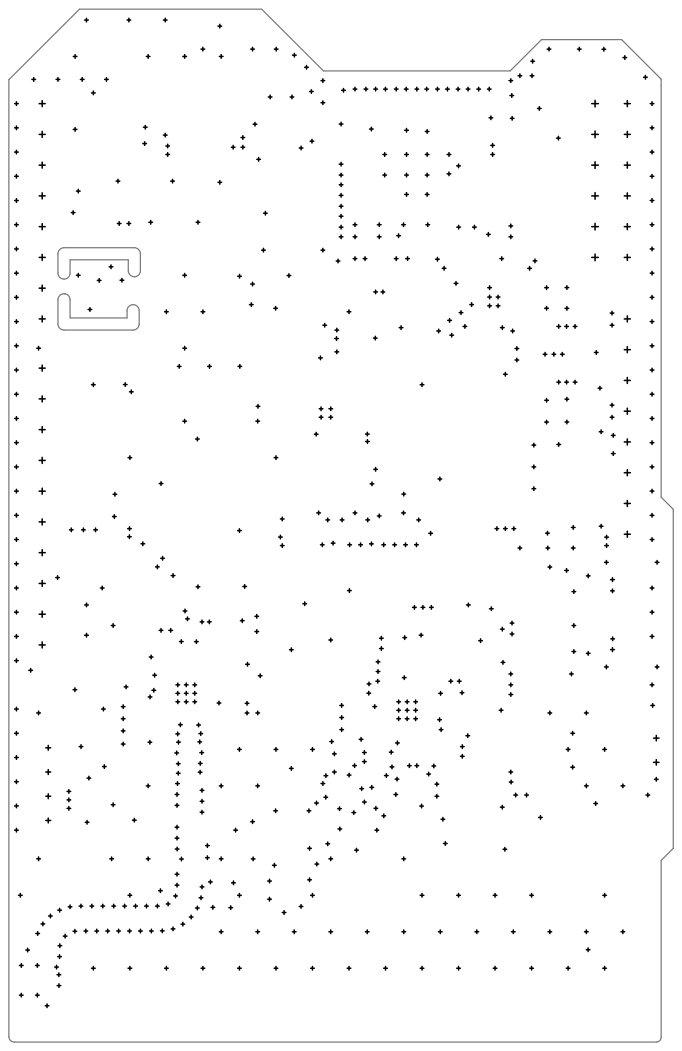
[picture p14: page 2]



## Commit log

2023-04-12 - Draft Schematic
    [BLOCK DIAGRAM.SchDoc, COVER PAGE.SchDoc, DOC REVISION HISTORY.SchDoc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]
2023-04-12 - Modify Ports and Pins connection
    [ESP32_S3.SchDoc, LoRa.SchDoc, SENSORS.SchDoc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]
2023-04-13 Add LCD
    [ESP32_S3.SchDoc]
2023-04-13 - Add LCD
    [LCD.SchDoc]
2023-04-13 -Remove interrupt pin from the air quality sensor
    [SENSORS.SchDoc]
2023-04-17 - Add GPS super cap - Add battery monitor circuit
    [ESP32_S3.SchDoc, GPS.SchDoc, LCD.SchDoc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]
2023-04-27 - PCB Components placement
    [ESP32_S3.SchDoc, GPS.SchDoc, LoRa.SchDoc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]
2023-05-02 - PCB Layout - ESP Pin swapping
    [ESP32_S3.SchDoc, GPS.SchDoc, LoRa.SchDoc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]
2023-05-03 - Add LED
    [ESP32_S3.SchDoc, POWER.SchDoc, SENSORS.SchDoc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]
2023-05-08 - Add pins description silkscreen - Fix Stemme connector pinout
    [ESP32_S3.SchDoc, GPS.SchDoc, LCD.SchDoc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]
2023-05-08 - Modify the assembly layer
2023-05-08 - Generate BOM
    [GPS.SchDoc, X2E Reference Sensor.PrjPcb]
2023-05-08 - Release Files
    [X2E Reference Sensor_Default_Bill of Materials.xlsx, X2E Reference Sensor_Default_Bill of Materials_Modified.xlsx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]
2023-05-08 - Add Layers order in the PCB
    [X2E Reference Sensor_Default_Bill of Materials.xlsx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]
2023-05-24 - Fix IO46/Boot to IO pin
    [ESP32_S3.SchDoc]
2023-06-09 - Change the F1 fuse with a smaller resistance
    [POWER.SchDoc]
2023-06-09 - Fix The LoRa sub-GHz switch control voltage by adding 220R R26
    [LoRa.SchDoc]
2023-06-09 - Add the INT1 signal from the accelerometer
    [SENSORS.SchDoc]
2023-06-12 - Change the Part number of J5 battery connector - Change the F1 fuse with lower resistance - NF R25 10K
    [POWER.SchDoc]
2023-06-13 - Fix the LoRa Antenna swapping - Reroute the SPI and CTRL after Swapping LoRa modules: IO48->SX1280_Busy, IO47->SX1280_SS, IO33->SX1280_DIO1, IO40->SX1280_nRES IO46->SX1261_Busy, IO41->SX1261_SS, IO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
    [ESP32_S3.SchDoc, GPS.SchDoc, LCD.SchDoc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]
2023-06-15 Added cutouts around the Humidity sensor. Optimized layout around the sensors. Made some small corrections to components arrangement. Added missing designation to SMPS components.
    [SENSORS.SchDoc, X2E Reference Sensor.PrjPcb]
2023-06-16 Made some adjustments on the Silkscreen layer. Increased clearance under the battery management IC.
    [POWER.SchDoc, X2E Reference Sensor.PrjPcb]
2023-06-16 Removed some DRC errors caused by silkscreen.
2023-06-30 Rotated the 868MHz antenna 180 deg to make the matching circuit more accessible.
    [LoRa.SchDoc, X2E Reference Sensor.PrjPcb]
2023-07-10 Swapped the Battery positive and negative terminal.
    [POWER.SchDoc]
2023-07-11 Resized the pictures/matchx x2e ref des pinout 1.png and pictures/matchx x2e ref des pinout 2.png
2023-07-12 Renumbered the schematic sheets
    [BLOCK DIAGRAM.SchDoc, COVER PAGE.SchDoc, DOC REVISION HISTORY.SchDoc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]
2023-07-12 Fixes to the assembly drawing layer. Removed old production files.
    [X2E Reference Sensor_Default_Bill of Materials.xlsx, X2E Reference Sensor_Default_Bill of Materials_Modified.xlsx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]
2023-07-12 - Update J4 & J5 Connector from our library - Arduino headers separation
    [ESP32_S3.SchDoc, POWER.SchDoc, SENSORS.SchDoc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]
2023-07-13 - Modify some designators - Add assembly layer to AN1 & AN2
    [ESP32_S3.SchDoc, LoRa.SchDoc, POWER.SchDoc]
2023-07-13 Minor adjustments to silkscreen and assembly layers.
    [X2E Reference Sensor.PrjPcb]
2023-07-13 Changed the designators of the arduino connectors.
    [ESP32_S3.SchDoc]
2023-07-14 Minor adjustments, created production files.
    [X2E Reference Sensor_Default_Bill of Materials.xlsx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]
2023-07-14 Changed IC9 GPIOT connection to GND for routing purposes. Modified PCB.
    [POWER.SchDoc]
2023-07-14 Regenerated ordering data. Changed all footprints to use metric holes.
    [X2E Reference Sensor_Default_Bill of Materials.xlsx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]
2023-07-14 Modified the Board outline layer to include cutout, added milling layer to gerbers, regenerated the gerbers.
    [X2E Reference Sensor_Default_Bill of Materials.xlsx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]
2023-07-14 Updated the job file to contain milling layer in gerbers.
2023-09-01 - Fix C32 & C33 Part numbers - Add part number to R26 - Fix the flipped Designators between R8 and R21 on the PCB top overlay
    [ESP32_S3.SchDoc, LoRa.SchDoc, X2E Reference Sensor_Default_Bill of Materials.xlsx]
2024-02-25 Made changes to PCB and schematic to facilitate the new form factor.
    [ESP32_S3.SchDoc, GPS.SchDoc, POWER.SchDoc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]
2024-02-25 some minor changes, silkscreen adjustments
2024-02-25 Fixed some errors after running DRC
    [X2E Reference Sensor_Default_Bill of Materials.xlsx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]
2024-02-25 Generated the production files
    [X2E Reference Sensor_Default_Bill of Materials.xlsx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]
2024-02-26 Changed the version of PCB and Schematic to 1.2
    [X2E Reference Sensor.PrjPcb, X2E Reference Sensor_Default_Bill of Materials.xlsx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]
2024-03-06 GPS.SchDoc - connected pin 7 of the module to V3P3_GPS through 0R, regenerated the production files.
    [GPS.SchDoc, X2E Reference Sensor_Default_Bill of Materials.xlsx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]
2024-03-06 Update BOM GPS module to GT-1110-UB7X.
    [X2E Reference Sensor_Default_Bill of Materials.xlsx]
2024-04-17 Changed polarity of J5, changed values of R4 and R5 to 3k9, R19 and R20 to NF, changed part number of the GPS module to GT-1110-UB7X.
    [GPS.SchDoc, POWER.SchDoc, SENSORS.SchDoc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]
